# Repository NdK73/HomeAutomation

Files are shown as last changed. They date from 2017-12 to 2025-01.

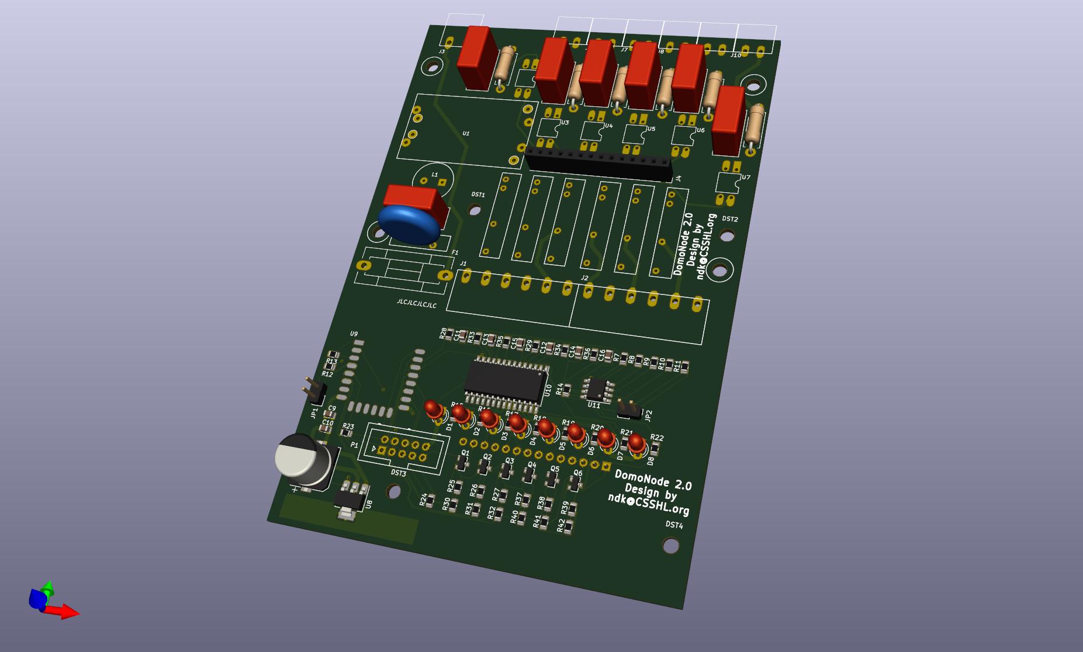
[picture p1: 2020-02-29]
domonode2.0/domonode2.0.jpg

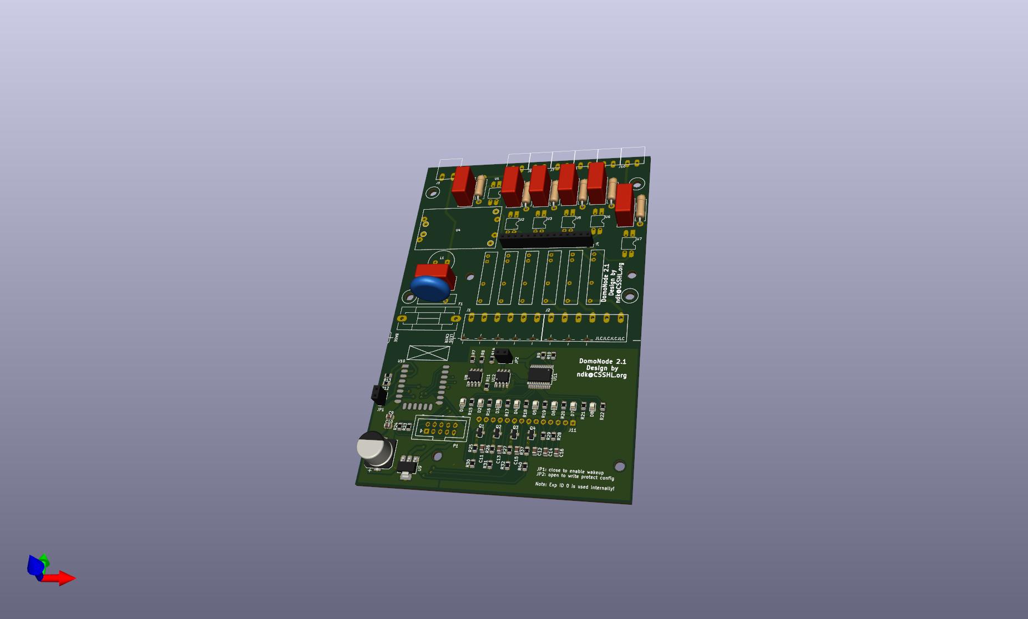
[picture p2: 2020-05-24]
domonode2/domonode2.jpg

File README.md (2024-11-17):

# HomeAutomation

This project consists of a protocol spec, the design files for physical nodes and the source code that glues it together.

## Protocol

[Full protocol description](protocol/protocol.txt) is available, together with examples of a [monitor](protocol/dom-monitor.py) and a [sender](protocol/dom-send.py). The protocol is text-based to ease debugging.

**ClearSky technology inside**: the basic concept is that **no coordinator** is needed for the nodes to work after the initial configuration. There must not be a single point of (catastrophic) failure. And obviously no "cloud" (hence **ClearSky**) service is needed either: you, and only you, decide if/when/which data can exit from your network!

The most critical element is currently the access point, that is so cheap that having a cold-standby one should not be a problem.

Messages must support authentication and encryption to guarantee that confidential packets or dangerous commands are actually sent from an authorized source.

**Warning**: protocol is still **work in progress** and **unstable**: non-backward-compatible changes are still possible! Only after 1.0.0 milestone changes that introduce incompatibilities will be delayed till 2.0.0 .

## HW

All HW designs were in [KiCAD](https://kicad.org/) 4.0.x (will follow what's packaged in latest [Ubuntu LTS](https://www.ubuntu.com/)) so not to require nonstandard installs. But 5.x introduced too many new features not to be used, and it's "easy enough" to install ([official instructions](https://kicad.org/download/ubuntu/)).

DIN-rail mounted devices are designed for the 6-modules [AK-DR-04C enclosure](https://www.aliexpress.com/item/-/1733706262.html). **Note:** these enclosures won't fit in a standard DIN rail box, unless you can move the rail further from the front panel (like in Gewiss GW40030).

Other devices are designed to be compatible with Vimar Plana series, but should fit other series with minor adjustements.

In the given layouts I use KF2EDGK **right-angle** (KF-2P, KF-4P or KF-6P) 5.08mm (or 3.81mm) pitch connectors so I can detach the node from power without having exposed wires with dangerous voltage laying around (and can reconnect it quickly and safely). Be sure to buy the angled version or you'll have a lot of extra work to bend the pins!

**Warning**: I did my best to keep the costs down without sacrificing security. Choice of the power brick is really important for security: **never** use HLK-PM01 clones unless you know what you're doing -- and even then it's better to avoid using 'em! If in doubt buy directly from [Hi-Link](http://www.hlktech.net/) (sorry, plain http, not https...). Probably the boards can't pass CE certification [only because of conducted emissions](https://skippy.org.uk/revisiting-the-hlk-pm01/), but since I don't have access to test equipment **use at your own risk** (or have 'em certified).

SSRs and relays should always be sourced from reputable sources. If in doubt, do not load 'em near the limits. For example never try a 400W load on a 2A SSR -- use a servo-relay. 2A SSRs are good for a couple of LED lamps, or a 40W bulb.

### [DomoNode](domonode) 1.1

A node based on ESP8266 to be mounted in a 6-modules DIN rail enclosure.

Provides 4 SSR outputs and an expansion bus connector.

[OSHW] IT000001 | [Certified open source hardware](https://oshwa.org/cert)

#### Errata

 - The text for GPIO4 and GPIO5 are reversed in the ESP12 symbol.

### [DomoNode 2](domonode2) 2.1 (WIP)

Evolution of DomoNode, but offers 6 inputs @ 230V, 6 SSR 2A@230V (each one have its own independent in and out lines, for maximum flexibility) and 8 independent LEDs, still in a 6-modules DIN rail enclosure. Kept SW compatibility with basic DomoNode (just the first 4 outputs), but different external connections.

To better follow the norms, now inputs are on the top and outputs at the bottom.

Same expansion bus connector as the DomoNode 1.1.

I kept 2mm between L and N lines and it **ought** to be double-insulation, but it's actually not required: the user can't touch anything that is not already expected to be at 230V (screws in connectors) without opening the enclosure (the expansion connector **MUST NOT** be exposed).

The board requires two v-cuts around the central part, drawn on ECO2 layer (but not visible in the image). Once the two boards gets separated, the smaller one have to be mounted over the bigger one, using 2 M3x25mm **plastic** spacers and suitable 1x14 pins headers (I used 2 1x14 female headers on the boards and 1x14 male pin strip with 21mm long pins to connect the two headers).

**Notes**:
 - Designed in KiCAD 5.1.5.
 - You can probably omit C8 quite safely

#### Errata

 - **Use 1k for R15-R22** or D1-D8 will burn after some months of use

#### Changes from (deprecated) [2.0](domonode2.0)
 - No glitches at powerup on outputs: all outputs are off until told otherwise by FW
 - Uses PCA9555 instead of MCP23017 (smaller, cheaper and already used for other expanders = smaller code footprint)
 - PCA9555 requires less components (pullups are included and outputs can directly drive SSRs)
 - wider traces (6mils were really too thin)
 - added socket for authentication chip (ATSHA204A or ATECC608A)
 - slightly moved connectors to better fit enclosure; probably some extra cuts to better accomodate connectors will be required anyway
 - replaced through-hole LEDs with SMD 0805 ones, better suited for light guides
 - highlighted pin 1 side for SMD IC footprints
 - corrected SDA and SCL pin assignment to use Wire.begin()
 - reduced confusing level semantics: relays and LEDs are ON when writing a HIGH level to the port (required to keep compatibility with FW for DomoNode 1.1), inputs are active when reading a LOW level (can be inverted via PCA9555)
 - used the PCB part with JLCPCB order number as a guide for LED holes: align "BASE" to the bottom of the concave part at the top of the box cover and use "LEDS CNTR" line to mark LEDs center line, then rotate the ruler and use markers on the short edges as a reference for the center line of the holes (the side opposite to "BASE" must be in contact with the right side of the concave part)
 - includes (yet untested) lightguides design files, ready to be sent to laser cutting service (use 5mm transparent plexiglas)
 - includes sample code (just add your FSM; webserver already accepts clicks on relay status to toggle it; config editing not yet implemented)

### [DomoNode-inout](domonode-inout) 1.1.1

An expansion node to be mounted in a 6-modules DIN rail enclosure.

Provides 4 SSR outputs, 3 220V opto-isolated inputs and 8 5V GPIOs.

Uses a PCA9555 for GPIOs and a 24C02 to store the expander config.

[OSHW] IT000002 | [Certified open source hardware](https://oshwa.org/cert)

### [DomoDisp](domodisp) 1.1

A node based on ESP8266 that provides physical user interface to the system.
Uses a 1.8" ST7735 LCD color display and a rotative encoder.
It is designed to be mounted either on the front of a DIN rail box, inside
a 4-modules Vimar Plana frame -- other frames could work but are untested, or
with the supplied enclosure in a 504 (4-modules) wall box.

Requires a 5V power source (possibly a DomoNode-inout, but a dedicated module
with power and relay will be published as soon as it's ready).

Includes sample "lib" for reading the encoder (needs cleanup... there still
are traces of experiments I did to read ESP's ADC from an interrupt routine).

The display can be managed by [TFT_eSPI](https://github.com/Bodmer/TFT_eSPI)
lib and works up to 27MHz (only 10MHz when testing on breadboard) -- remember
to edit User_setup.h before compiling your sketch!

[OSHW] IT000003 | [Certified open source hardware](https://oshwa.org/cert)

#### Errata

 - The text for GPIO4 and GPIO5 are reversed in the ESP12 symbol.

### [DomoDispV2](domodisp2) 2.0

**Future** release using shared SPI bus for display, freeing 2 GPIOs. One of
the freed GPIOs is used to control dimming.

**WARNING**: FW is incompatible with old DomoDisp!

### [DomoNode-inputs](domonode-inputs) 1.0

WIP - Still untested !

An expansion board with 11 inputs @ 220V and 5 low-voltage IOs.

When inputs are powered from 220V they get read as logic low.
Low-voltage inputs are directly connected to PCA9555 lines so there's a weak
(100k) pullup active at powerup. If you want to use 'em as outputs remember
to use inverted logic to avoid glitches at powerup.

### [DomoSwitch](domoswitch) 1.0

WIP / On hold (I'd need to source a suitable front panel, first)

A node that hosts 2 relays (or SSRs -- double footprint), 2 pushbuttons and 2
RGB LEDs. Split in 3 sub-boards to fit behind a 2-modules
[Vimar Plana 14042 hole cover](https://www.vimar.com/it/it/catalog/product/index/code/14042).

The buttons and LEDs are placed so that they match the markers inside the 14042
cover, simplifying the assemply.

To be compliant with SeeedFusion rules, I had to split the 3 sub boards as different designs.
Then I simply combined the sub-boards to better use the 100x100mm area. That means that for
$15 plus shipping I get 40 complete boards... I hope it doesn't require major mods!

**TODO**: support to enclose the dangerous sub-boards (I'll have to prototype it
with a 3D printer, but will need a resin cast for the final version).

### 3rd-party devices

It's obviously possible to support 3rd-party devices like SonOff, Shelly, touch switches and so on.
Reversing and further info is usually published first on [my site](https://csshl.net) (mostly Italian-only)

## SW

Still work in progress.

A sketch with [partial protocol implementation](https://github.com/NdK73/Domotic)
is under test.

Expansions (DomoNode-inout, DomoNode-inputs) are autodetected and (mostly)
autoconfigured by library. The algorithm is:
  - for each I2C bus address from 0x50 to 0x57
    - if slave found at 0x5X:
      - determine memory size:
        - try reading location 0-4 using 8-bit address (24LC02)
        - try re-reading the same locations, still using 8-bit addresses
        - both reads are equal => 8-bit addresses
        - else
          - set flag for 16-bit addresses
          - read locations 0-4 using 16-bit address (that would overwrite
          location 0 in 8-bit devices, but we already ruled out this
          is a 8-bit one...)
      - check first two bytes for 'magic' constant; if wrong, go to next
          address: not a device we can handle (possibly uninitialized)
      - read device config from it
    - if slave is not found at 0x5X, test if a slave is present at 0x2X
      (PCA9555 in DomoNode-inout 1.0)
      - if PCA9555 is found, create a fake config for 4 outs and 3 ins (TODO:
        how to handle other GPIOs?)
    - instantiate the correct device class

This algorithm assumes the memory have already been initialized.
The EEPROM must contain at least these 16 bytes:
  - 0x00 2 bytes 'magic' 0xD74A (0xD7 in 0x00 and 0x4A in 0x01)
  - 0x02 1 byte Expansion type (Official "registry" is kept in lib sources)
  - 0x03 1 byte Release code (every new HW release increments the release code)
  - 0x04 4 bytes "unique" board ID
  - 0x08 8 bytes reserved

The remaining space is used as defined by device class (usually for IO
configuration and descriptions).
The board ID must be "unique enough" so that the master node can detect that an
expansion have been changed and invalidate the old mappings.

## [Crypto HW](SecurityChips/)

I added to the repository all the informations I found re: security chips that could be used w/o signing NDAs. The list is probably incomplete.

I'm currently working on ATECC608A, trying to reverse engineer the information that would require signing NDA (why, Microchip? WHY??? you opened the docs for the 508...)

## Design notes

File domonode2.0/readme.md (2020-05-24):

## DomoNode 2.0

**Do not use:**. This folder is just for reference.

Evolution of DomoNode, but offers 6 inputs @ 230V, 6 SSR 2A@230V (each one have its own independent in and out lines, for maximum flexibility) and 8 independent LEDs, still in a 6-modules DIN rail enclosure. Kept SW compatibility with basic DomoNode (just the first 4 outputs), but different external connections.

Same expansion bus connector as the DomoNode 1.1.

I kept 2mm between L and N lines and it **ought** to be double-insulation, but it's actually not required: the user can't touch anything that is not already expected to be at 230V (screws in connectors) without opening the enclosure (the expansion connector **MUST NOT** be exposed).

The board requires two v-cuts around the central part, drawn on ECO2 layer (but not visible in the image). Once the two boards gets separated, the smaller one have to be mounted over the bigger one, using 2 **plastic** spacers (M3x15mm) and suitable 1x14 pins headers.

**Note**: Designed in KiCAD 5.1.5.

#### Known Problems

Fixed in v2.1:
 - **EPIC FAIL**: pulldowns instead of pullups on SDA and SCL :( -- it seems to work OK with internal ones, but could be a bit less stable
 - **FIXABLE FAIL**: SDA and SCL are reversed -- use Wire.begin(5,4);
 - Possible glitches at powerup on outputs: after a short power fail (~5s) MCP23017 outputs remain in the last state till setup() resets 'em (or indefinitely if you enter programming mode)
 - Trace for 3v3 to expansion connector is too thin
 - Traces from SSRs to Qn and from Qn to GND are too thin
 - Many traces are too long (to avoid vias)
 - You'll have to cut out about 2mm from the top of the break-out zone to allow the locks on the removable part of the connectors to engage

No need to fix in 2.1:
 - MCP23017 reset line goes to 3v3 instead of 5V

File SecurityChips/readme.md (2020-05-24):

# Security Chips

This folder contains developement notes and references to the needed personalization of the supported security chips (coprocessors).

## Included

Nothing yet. SW only.

## WIP

### ATECC608A

I2C address: **0x60**

16 key slots, supporting
 - NISTP256 curve for ECDH, key-derivation and signature
 - AES keys
 - Secrets for SHA

Since full datasheet is not freely available for ATECC608A, the results are obtained by reverse engineering from the publicly available datasheets and code:
 - [ATSHA204A official datasheet](ATSHA204A-Data-Sheet-40002025A.pdf)
 - [ATECC508A **full** datasheet](ATECC508A.pdf)
 - [ATECC608A **brief** datasheet](ATECC608A_(brief).pdf) (too bad the full one is under NDA)
 - [Microchip AN2589](ATECC608A-AN2589.pdf) for some more details about config area changes
 - [SparkFun_ATECCX08a_Arduino_Library](https://github.com/sparkfun/SparkFun_ATECCX08a_Arduino_Library)
 - Microchip's [cryptoauthlib](https://github.com/MicrochipTech/cryptoauthlib) and [cryptoauthtools](https://github.com/MicrochipTech/cryptoauthtools/)
 - [atecc608a python lib source](https://github.com/ergo70/atecc608a)
 - [ECC608-AES-GCM-Test](https://github.com/kmwebnet/ECC608-AES-GCM-test)

Slot allocations:
 - 0: device private key for attestation (ECDH=0, Internal sigs=1, External sigs=0), **must be locked after generating key**
 - 1: device private key for ECDH (ECDH=1, Internal sigs=0, External sigs=0), **must be locked after generating key**
 - 2: 1st base station's PK for ECDH
 - 3: 2nd base station's PK for ECDH
 - 4: Master secret 1 (node-bs1) (written by ECDH 1+2)
 - 5: Shared key 1 (derived from key 4 via KDF)
 - 6: Master secret 2 (node-bs2) (written by ECDH 1+3)
 - 7: Shared key 2 (derived from key 6 via KDF)
 - 8-15: Group secrets for SHA

Generate device attestation certificate:
 - generate key 0: GenKey(0b00001100 /* Generate digest in TmpKey, new random private key */, 0x0000 /* Keyslot * */ ), check return value (might fail); save returned pubkey (64 bytes, X,Y)
 - generate self signed certificate: Sign(0x80 /* InternalSig */, 0x0000 /* Keyslot 0 */); save result (64 bytes, R,S)

Verify device attestation certificate:
**TODO**

#### Python code

The code uses 

## TBD

### ATSHA204A

I2C address: **0x64**

Not being able to do actual crypto, it requires  **secure initialization** of the shared secret.
Depending on your security requirements it can range from easy to very difficult.

References:
 - [ATSHA204A official datasheet](ATSHA204A-Data-Sheet-40002025A.pdf)

### SE050

NXP SE050 (SE050C1 variant) is in a not very hobbyst-friendly package but supports all ECC curves, including Curve25510/Ed25519, **and** RSA up to 4096 bits.
A1 variant only supports ECC curver, B1 variant only RSA.

### DS2477 / DS28C50

Just supports SHA3 for authentication, no crypto. Similar to ATSHA204, but from Maxim.

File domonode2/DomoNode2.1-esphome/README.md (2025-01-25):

# Use DomoNode 2.1 from ESPHome

Recently ESPHome started supporting TCA9555 expander (currently input changes are not reported, see [this thread](https://github.com/esphome/issues/issues/6438#issuecomment-2560802722) for a fix): that greatly simplifies integrating a DomoNode 2.1 in Home Assistant.

The HW template to use is [DomoNode21.yaml](DomoNode21.yaml) . Just save it under esphome/ folder (I usually store board definition files in esphome/boards/DomoNode/) and create your device as:

    substitutions:
      device_name: test
      upper_devicename: Test
    
    packages:
      domonode: !include boards/DomoNode/DomoNode21.yaml
    
    esphome:
      name: $device_name
    
    # Enable Home Assistant API
    api:
      encryption:
        key: "useASecureKey"
      reboot_timeout: 0s
    
    ota:
      - platform: esphome
        password: "BetterHaveAGoodKeyHereToo"
    
    # A web page is useful...
    web_server:
      port: 80
      version: 2
    
    # You can also override the settinsg like:
    output:
      - id: !extend led1
        invert: true
    light:
      - id: !extend rl1
        name: "Main Power line"

EEPROM is also supported by [this component](https://github.com/pilotak/esphome-eeprom), just add to your yaml this snippet:

    external_components:
      - source: github://pilotak/esphome-eeprom
        components: [i2c_eeprom]
    
    i2c_eeprom:
      - id: eeprom0
        size: 2KB # Default mainboard memory (kilobits!)
        #address: 0x50

Too bad there's no support (yet) for the crypto chip.

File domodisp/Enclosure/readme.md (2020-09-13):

# DomoDisp Enclosure

In this folder you can find the enclosure I designed for DomoDisp both in FreeCad and STL formats.

It's sized for a 504 (4-modules) wall box.

I printed Front.stl "upside down". If your settings are OK for the filament you're using, it should print well w/o supports.

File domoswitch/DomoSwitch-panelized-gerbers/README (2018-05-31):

Used Panelizer (from GerberTools).
Requires renaming two files from KiCad's plots: .gm1 to .gml and .drl to .txt *before* combining boards.

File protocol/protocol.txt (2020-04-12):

Domotic protocol (version 0.1.1)
================================

When using IP as transport layer, every node must have its own address and must be able to receive and send data *only* from/to the local network.
This protocol is *not* intended to be exposed to the Internet, even if some (limited) coutermeasures are implemented: multicast TTL is 1, longer answers require authenticated requests, etc. If accessibility from the Internet is needed, a gateway with proper security measures (SSL encryption, proper authentication, etc) *must* be used. The gateway can translate to other protocols, too.
The packet format is constrained by UDP on ESP8266 (reference platform) that allows at most 1472 bytes per UDP packet (a single Ethernet frame).

Default UDP port used is 55114. Default multicast address used is 239.255.215.74 (see RFC2365 "The IPv4 Local Scope", the last two octects are the integer 55114).
If needed, "fake" MAC addresses can be generated as 4e:64:4b:xx:yy:zz ('N':'d':'K':xx:yy:zz) -- least significant bits of first octect are '10', that means "locally administerd (1)" and "unicast (0)".

Every node in the network is configured with an unique ID ('sender'). 0x0000 means "unconfigured" and 0xFFFF is reserved.

Every IO line MUST be member of a groupID (see maps in registers 0x20-0x23), that is used to report its changes. ID 0000 is reserved for unconfigured IOs that MUST NOT be reported. GroupID allocation strategy is instance-specific and not covered by protocol.

Allowed characters for strings in array elements are [a-zA-Z0-9.:_-] .

Data coming throught the serial port during the initial configuration (after a hard config reset -- usually a 10-seconds press of a protected button) is considered signed and encrypted (but it's actually unsigned plaintext).

Display-enabled devices MIGHT handle "widgets" (bars, icons) as output ports (both analog and digital). If message is longer than allowed the device MUST show at least the first max_msg_len characters and MIGHT use scrolling to display the whole message.

A packet is defined as:

Pkt := UnicastPkt | MulticastPkt
UnicastPkt := RequestPkt | AnswerPkt

RequestPkt is sent from a client to a server to initiate an operation.

RequestPkt := SimplePkt | SignedPkt | EncPkt
  SimplePkt := CommandPacket | InfoPacket
    CommandPacket := <'C'> {DigitalOutSpec | AnalogOutSpec | RegisterSpec}
      DigitalOutSpec := <'D'> <output#:ByteHex> <'0'|'1'|'T'>
      AnalogOutSpec := <'A'> <input#:ByteHex> <value:WordHex>
        WordHex := <hibyte:ByteHex> <lobyte:ByteHex>
      RegisterSpec := <'R'> <reg#:ByteHex> <0x20-0x7f>* // Till end of line or end of packet; register-specific parsing required
    InfoPacket := <'I'> {DigitalReadSpec | AnalogReadSpec | InfoSpec | RegisterReadSpec}
      DigitalReadSpec := <'D'> <'I'|'O'> <io#:ByteHex>
      AnalogReadSpec := <'A'> <'I'|'O'> <io#:ByteHex>
      InfoSpec := <'I'> <'A'|'D'> <'I'|'O'> <io#:ByteHex>
      RegisterReadSpec := <'R'> <reg#:ByteHex> [<arrayelement#:ByteHex>]
  SignedPkt := <'S'> <keyID:WordHex> <signature:Array<ByteHex>> SimplePkt // TODO
  EncPkt := <'E'> <keyID:WordHex> <payload:Array<ByteHex>> // Payload can be either SignedPkt or SimplePkt, and MUST be encrypted under given key; TODO

  ByteHex := <0-9|A-F><0-9|A-F>  // Max 256 'lines' per type

AnswerPkt is sent from a server to the client that sent a RequestPkt. If it's sent, it MUST be addressed to the same IP and port that originated the RequestPkt.

In SignedPkt (and the following SignedUpdatePkt) the signature covers only payload data (SimplePkt or EventSpec), *NOT* including termination character (CR or \x00).

TODO: handle encryption (should use the same key as in request, if possible: what happens when using pubkeys?)

AnswerPkt := <'A'> ErrorCode AnswerSpec
  ErrorCode := <err:ByteHex>
  AnswerSpec := <''> | <current status string depending on received SimplePkt>

Nonzero 'err' reports an error and AnswerSpec must be empty.
If err is zero, AnswerSpec depends on SimplePkt:
  CD: <'W'> <'D'> <'0'|'1'>
  CA: <'W'> <'A'>
  CR: <'W'> <'R'>
  ID: <'R'> <'D'> <'0'|'1'>
  IA: <'R'> <'A'> <value#:WordHex>
  IR: <'R'> <'R'> {<'L'> <len:ByteHex> | <'V'> <0x20-0x7f>*}
  II: <'R'> <'I'> {InfoBool | InfoPercent | InfoTemp | InfoPower | InfoUserFloat | InfoText} <descr:<0x20-0x7f>*>
    InfoBool := <'B'>                                                   // Used for digital lines
    InfoPercent := <'%'> <decimals:0-3>
    InfoTemp := <'K'> <decimals:0-2>                                    // By default room temperatures are reported in centi-Kelvin (K2)
    InfoPower := <'W'> <decimals:0-2>                                   // Power in Watts (0.00 to 65535) -- usually home appliances use decimals=0 (1W resolution)
    InfoUserFloat := <'F'> <numerator:WordHex> <denominator:WordHex>    // Float=(numerator*regvalue)/(denominator*65536); note that result is strictly < numerator/denominator
    InfoText := <'T'> <maxlen:ByteHex>

MulticastPkt can be generated either in response to some external event (a change in temperature, a timer expiring, ...) or in response to a RequestPkt.
Nodes can listen to multicast packets to update their state or act in response to events happened on other nodes (f.e. a light turns on when a button on another node is pressed).

Note that setting the node HW config (which lines are inputs, which are outputs, their names and characteristics, etc) is outside the scope of this protocol, and nodes should not allow remote changes.

MulticastPkt:= UpdatePkt | SignedUpdatePkt
  SignedUpdatePkt := 'S' <keyID:WordHex> <signature:urlsafe_base64_string> UpdatePkt
  UpdatePkt := <'U'> EventSpec
    EventSpec := InEvent | OutEvent | TimeEvent
      InEvent := <'I'> {DigitalEvent | AnalogEvent}
        DigitalEvent := <'D'> <group:WordHex> <'0'|'1'>
        AnalogEvent := <'A'> <group:WordHex> <value:WordHex>
      OutEvent := <'O'> {DigitalEvent | AnalogEvent}
      TimeEvent := <'T'> <epoch:ByteHex> <hictr:WordHex> <loctr:WordHex> <tz_dst:ByteHex>

Analog values are represented as an unsigned 16-bits word. Temperatures should be converted in centi-Kelvin unless peculiar needs require otherwise.

TimeEvent is usually generated periodically (at least every minute, up to once per second) by a coordinator node with access to accurate timekeeping HW and/or external sources (NTP, GPS, etc). The only epoch currently defined is 00 (for Unix epoch: seconds since Jan, 1, 1970 -- will last till Jan 2106), hictr and loctr are a single 32-bit counter. tz_dst packs timezone relative to GMT in lower 5 bits (signed) and if dst is active or not in bit 5. Bits 6 and 7 are reserved and must be 0. Security-sensitive nodes must sanitize it (checking that it does not deviate too much from internal clock, adding sequence numbers to packets sent during the same second, etc) and should only trust signed updates. Time needed for signature verification *must not* "shift" the timestamp (in other words the timestamp references the second the packet have been received, not the one it gets processed).

Only "meaningful" AnalogEvent should be reported. The meaningfulness of the change is application- and sensor-specific. For example, it's usually useless to report every .01°C change in temperature for a room, but only a .1°C change -- or even a 2°C one if you're using a DHT11 (2°C error!). Rule of thumb: don't send more than a report every 10 seconds or so for a single entity to avoid flooding the network with useless data.

Registers
=========

When reading register containing arrays, if the optional argument is omitted, only the array len is returned. If the optional argument is given, then the actual element is returned.

Every write to registers must be inside a signed packet.

Changes to register contents must be saved to permanent storage before returning answer packet.

00: node info
    READ: string: "protocol_version digital_outs analog_outs digital_ins analog_ins max_txt_len utf8_support"; protocol_version is currently "0.1.1", numbers in *decimal*, utf8_support as 'T' or 'F'
    WRITE: (requires a signed packet *and* 'sender' still 0x0000) sets 'sender' (node-ID)
01: node keys & supported algorithms
    READ: Array<String>: "<keyID:WordHex>:algo=key_handle;uses", algo:='ec25519'(key exchange)|'ed25519'(sign)|'nistp256'(HW-backed, f.e. in ATECC608A)|'aes-enc'|'aes-mac'|'unset'; empty array means neither authentication nor encryption are supported, else number of slots tells the number of keys that can be used; key_handle for public and private keys is the public key (you can say if the priv key is available by looking at key usage), for secret keys is just a key handle (FIXME: define how it's generated), if the key is not yet set but the slot is reserved for a certain algo, handle can be empty; 'uses' is a string of one or more permitted uses for the given key: 'e'ncrypt, 'k'ey agreement, 's'ignature, 'v'erify signature (only pubkey is present); keys can only be set using encrypted packets or OOB; keyID 0000 is reserved for the NULL method (signature generates a sequence of 128 '0', encryption copies the source string) and *MUST* be refused in production builds; keyID FFFF is reserved and can not be used
02: hostname (short)
    READ: string: "<hostname> (<build_ID>)"
    WRITE: string, max 64 characters ([a-z0-9-], see RFC1123)
03: flags; WordHex, TODO (UdpReportEnable?) -- currently RESERVED
04: network info
    READ: string: "WIFI:SSID,ip" | "ETH:ip" | "BUS:nodeID"
    WRITE: string: "WIFI:SSID,password[,ip,mask]" (must also be encrypted) | "ETH:DHCP|ip,mask" | "BUS:nodeID" (bus must be on a different port than config interface)
05: display message
    READ: string
    WRITE: string, max max_txt_len (from R0) printable-ASCII characters (0x20-0x7e) for message
06-1f: reserved
20: digital out port map
    READ: Array<WordHex> : current mapping of digital outs
    WRITE: Array<WordHex> : sets new mapping of digital outs
21: analog out port map
    READ: Array<WordHex> : current mapping of analog outs
    WRITE: Array<WordHex> : sets new mapping of analog outs
22: digital in port map
    READ: Array<WordHex> : current mapping of digital ins
    WRITE: Array<WordHex> : sets new mapping of digital ins
23: analog in port map
    READ: Array<WordHex> : current mapping of analog ins
    WRITE: Array<WordHex> : sets new mapping of analog ins
24: (Array<Event>) events
25: (Array<?>) timer actions TODO
26: (Array<WordHex>) timers intervals; most significant nibble is: 0=Monostable|1=Astable, 00=milliseconds, 01=seconds, 10=minutes, 11=hours, 0=RESERVED; the remaining 12 bits define the actual interval
27-ff: reserved

/*************************************

 TO BE RETHOUGHT COMPLETELY !

 ||||||||||||||||||||||||||||
 vvvvvvvvvvvvvvvvvvvvvvvvvvvv

Events and timers
=================

An "event" is the reaction of a node to a *multicast* message, irregardless if it's being transmitted or received. Unicast messages don't trigger event processing.

A timer is a node-private object that (obviously) keeps track of time. It can only be started (starts from the definition in R27) and gets decremented automatically every tick (.1s = 10Hz). When it reaches 0, it fires an event. Timers need not to be very accurate (+/- a tick is still OK). Setting a timer to 0 disables it *without* firing an event. Only a single action is allowed for a timer.

Events are thought for simple actions ('turn off a light after 30 seconds'). Complex scenarios COULD be coordinated by a management node (that COULD offer a more user-friendly interface or even a programmatic one). Anyway "semi-complex" scenarios are possible even with only a limited amount of events.

Event := GroupID Condition {DigitalOutSpec | AnalogOutSpec | TimerSpec}
  Condition := <'-'> | EventCond | Timer
    EventCond := EventSpec [<'<'> | <'>'> | <'='>]  // Default is '='
    Timer := <'T'> ByteHex
    TimerSpec := Timer {<'0'> | <'1'>]
TimerEvent:= Timer DigitalOutSpec

The first match is on groupID. The second match is on Condition. '-' means the action is executed without checking anything.

Examples (spaces added for readability):
// Stepper: toggles out1 state every time digital input 4 of group 1234 goes low
1234 ID04 0      D01 T
// Control heating system with hysteresis
ABCD IA01 21C0 > D03 0  // Turn off heating if temp > 21.0°C
ABCD IA01 17C0 < D03 1  // Turn on heating if temp < 17.0°C
// Toggle out2 when in7 of node 4567 goes low for more than 1s (R28 must contain "..,..,0A,...")
4567 ID07 1      T02 0  // 4567:din7 is high: disable timer2
4567 ID07 0      T02 1  // start timer2 (multicast is sent only when the signal is changing)
T02  D02 T              // timer2 fires: toggle out2

// --Not working-- Watchdog: other nodes are powered only when out1=1
// Note that T00 is only started once a packet arrives, so even if the AP takes 10minutes to come back online it's not a problem!
*    -      T00 0384   // restart timer 00 every time a multicast packet arrives; fires after 90s (900 = 0x0384)
!    T00    D01 0      // when timer0 fires, out1 gets reset
!    T00    T01 000A   // ... and timer1 is started (1s)
!    T01    D01 1      // When timer1 expires, out1 returns to 1

*/

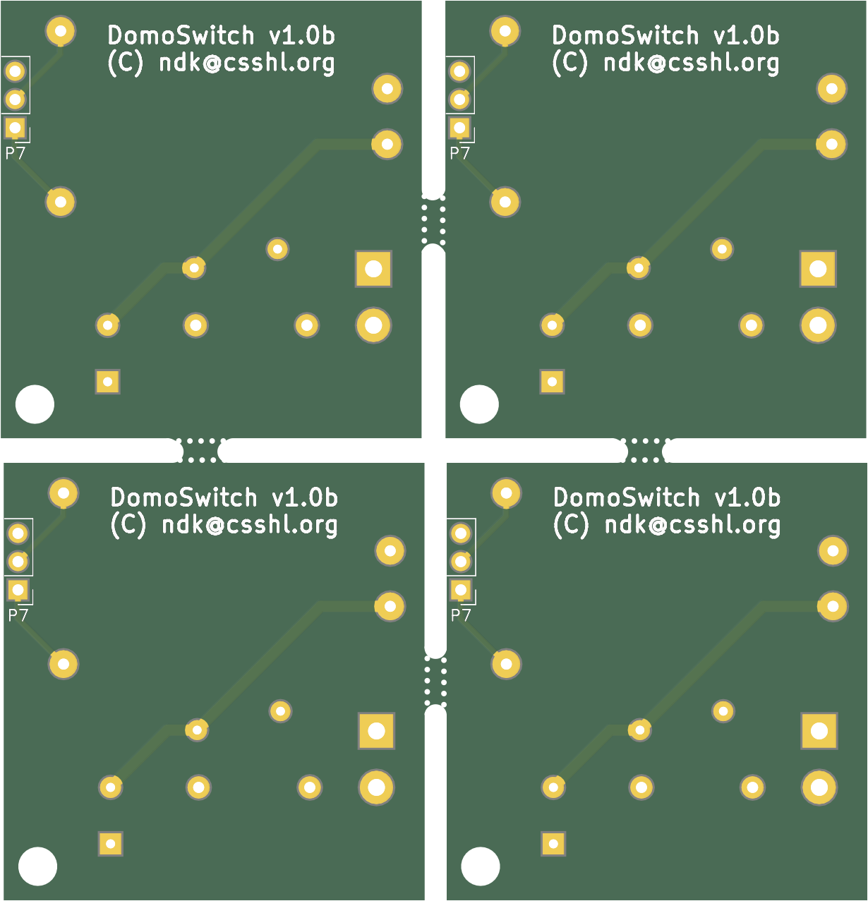
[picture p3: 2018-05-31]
domoswitch/DomoSwitch-panelized-gerbers/DomoSwitch-2_Bottom.png

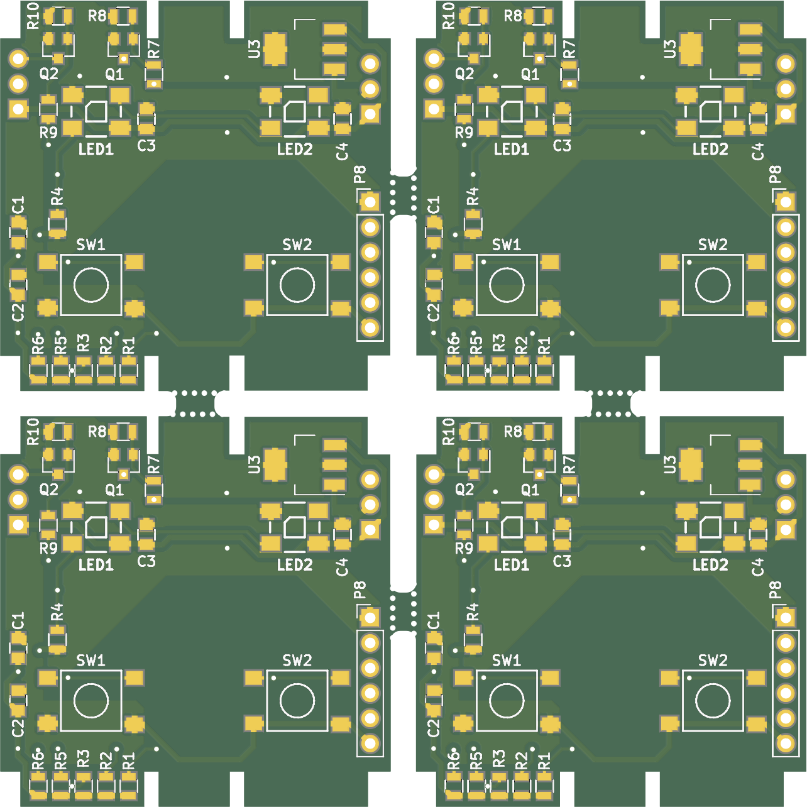
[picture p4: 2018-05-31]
domoswitch/DomoSwitch-panelized-gerbers/DomoSwitch-1_Top.png

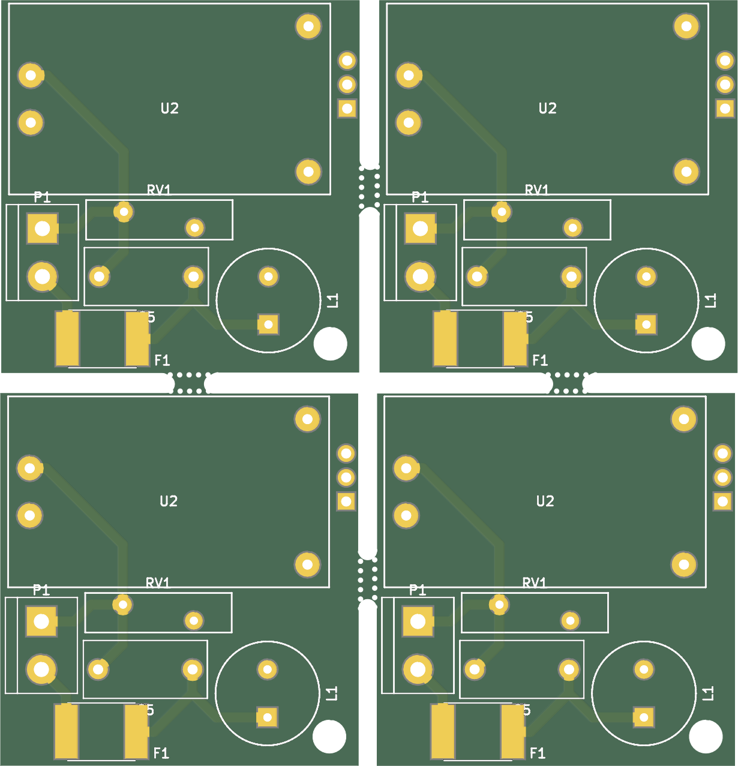
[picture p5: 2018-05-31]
domoswitch/DomoSwitch-panelized-gerbers/DomoSwitch-2_Top.png

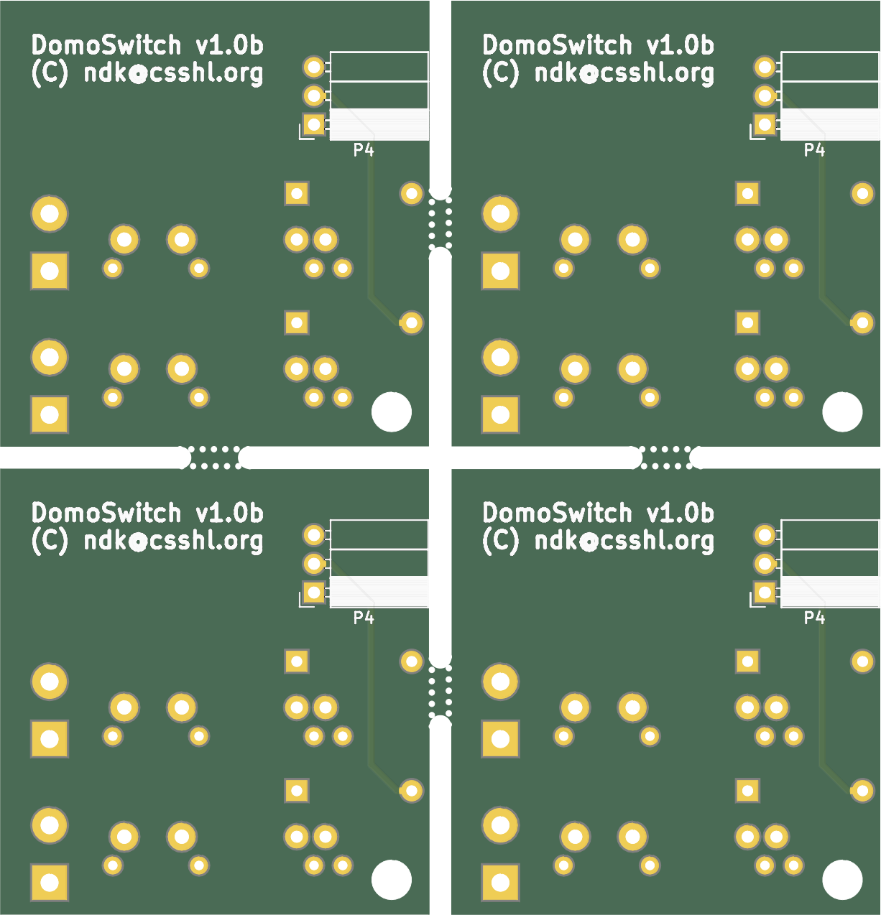
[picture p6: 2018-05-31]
domoswitch/DomoSwitch-panelized-gerbers/DomoSwitch-3_Top.png

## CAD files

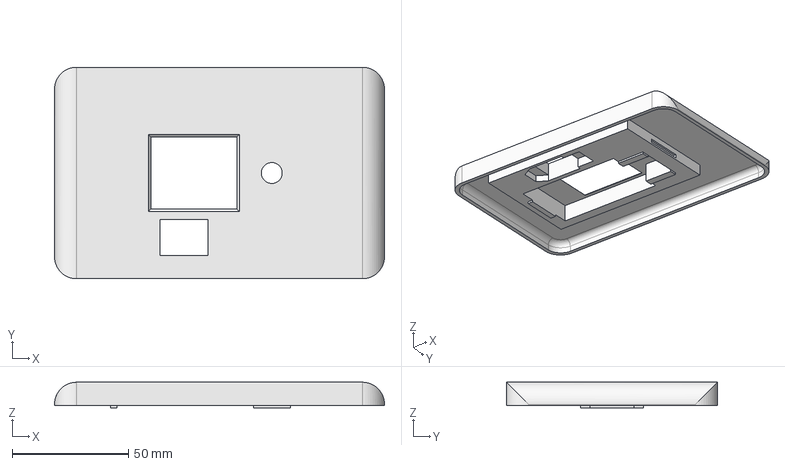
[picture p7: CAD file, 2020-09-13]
domodisp/Enclosure/Front.FCStd
142.0 x 91.0 x 11.0 mm

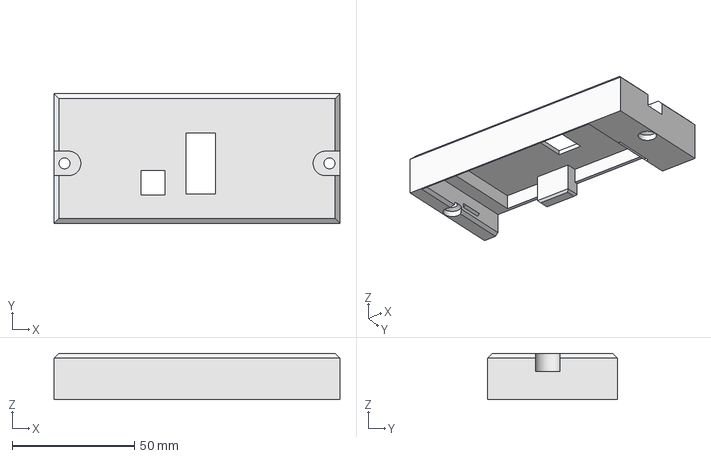
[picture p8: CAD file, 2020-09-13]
domodisp/Enclosure/Support.FCStd
117.0 x 53.0 x 19.0 mm

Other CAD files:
domodisp/Enclosure/Front.stl
domodisp/Enclosure/Support.stl

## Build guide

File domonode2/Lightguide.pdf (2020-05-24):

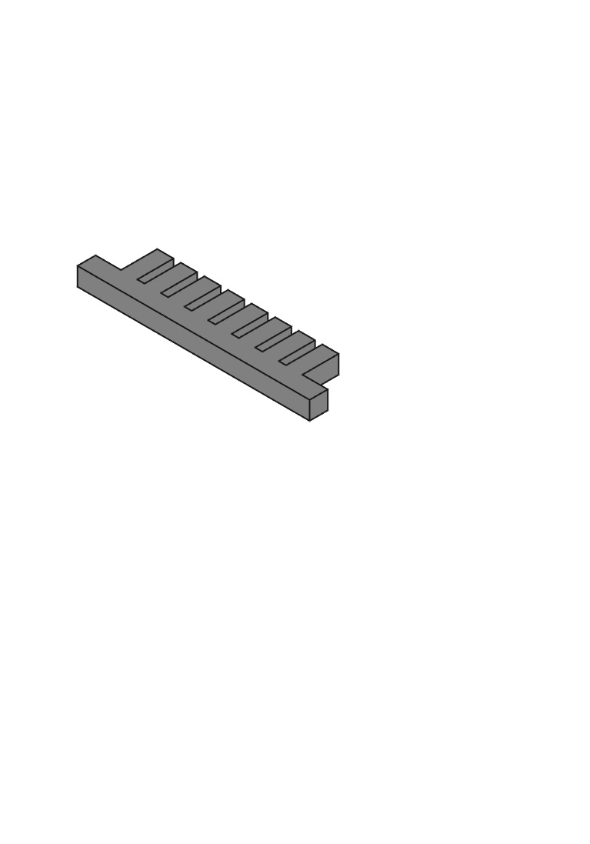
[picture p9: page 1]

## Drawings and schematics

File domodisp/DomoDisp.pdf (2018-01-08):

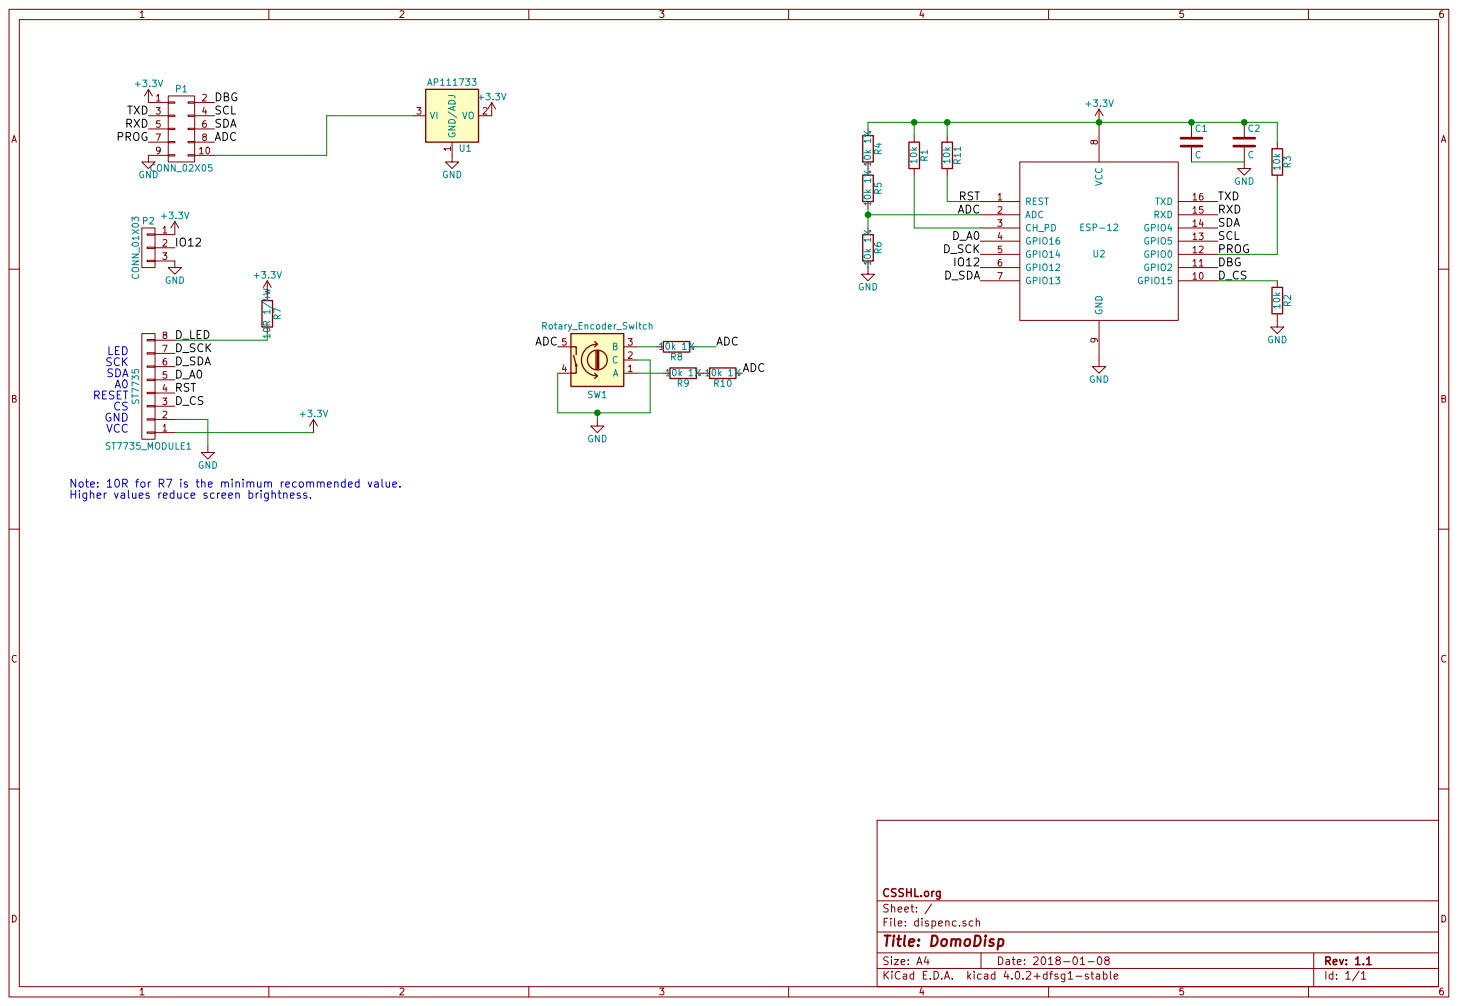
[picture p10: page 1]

9 GPIO15 10 GPIO2 11 GPIO0 12 GPIO5 13 GPIO4 14 RXD 15 TXD 16 U2 ESP-12 GND

File: dispenc.sch Sheet: / CSSHL.org

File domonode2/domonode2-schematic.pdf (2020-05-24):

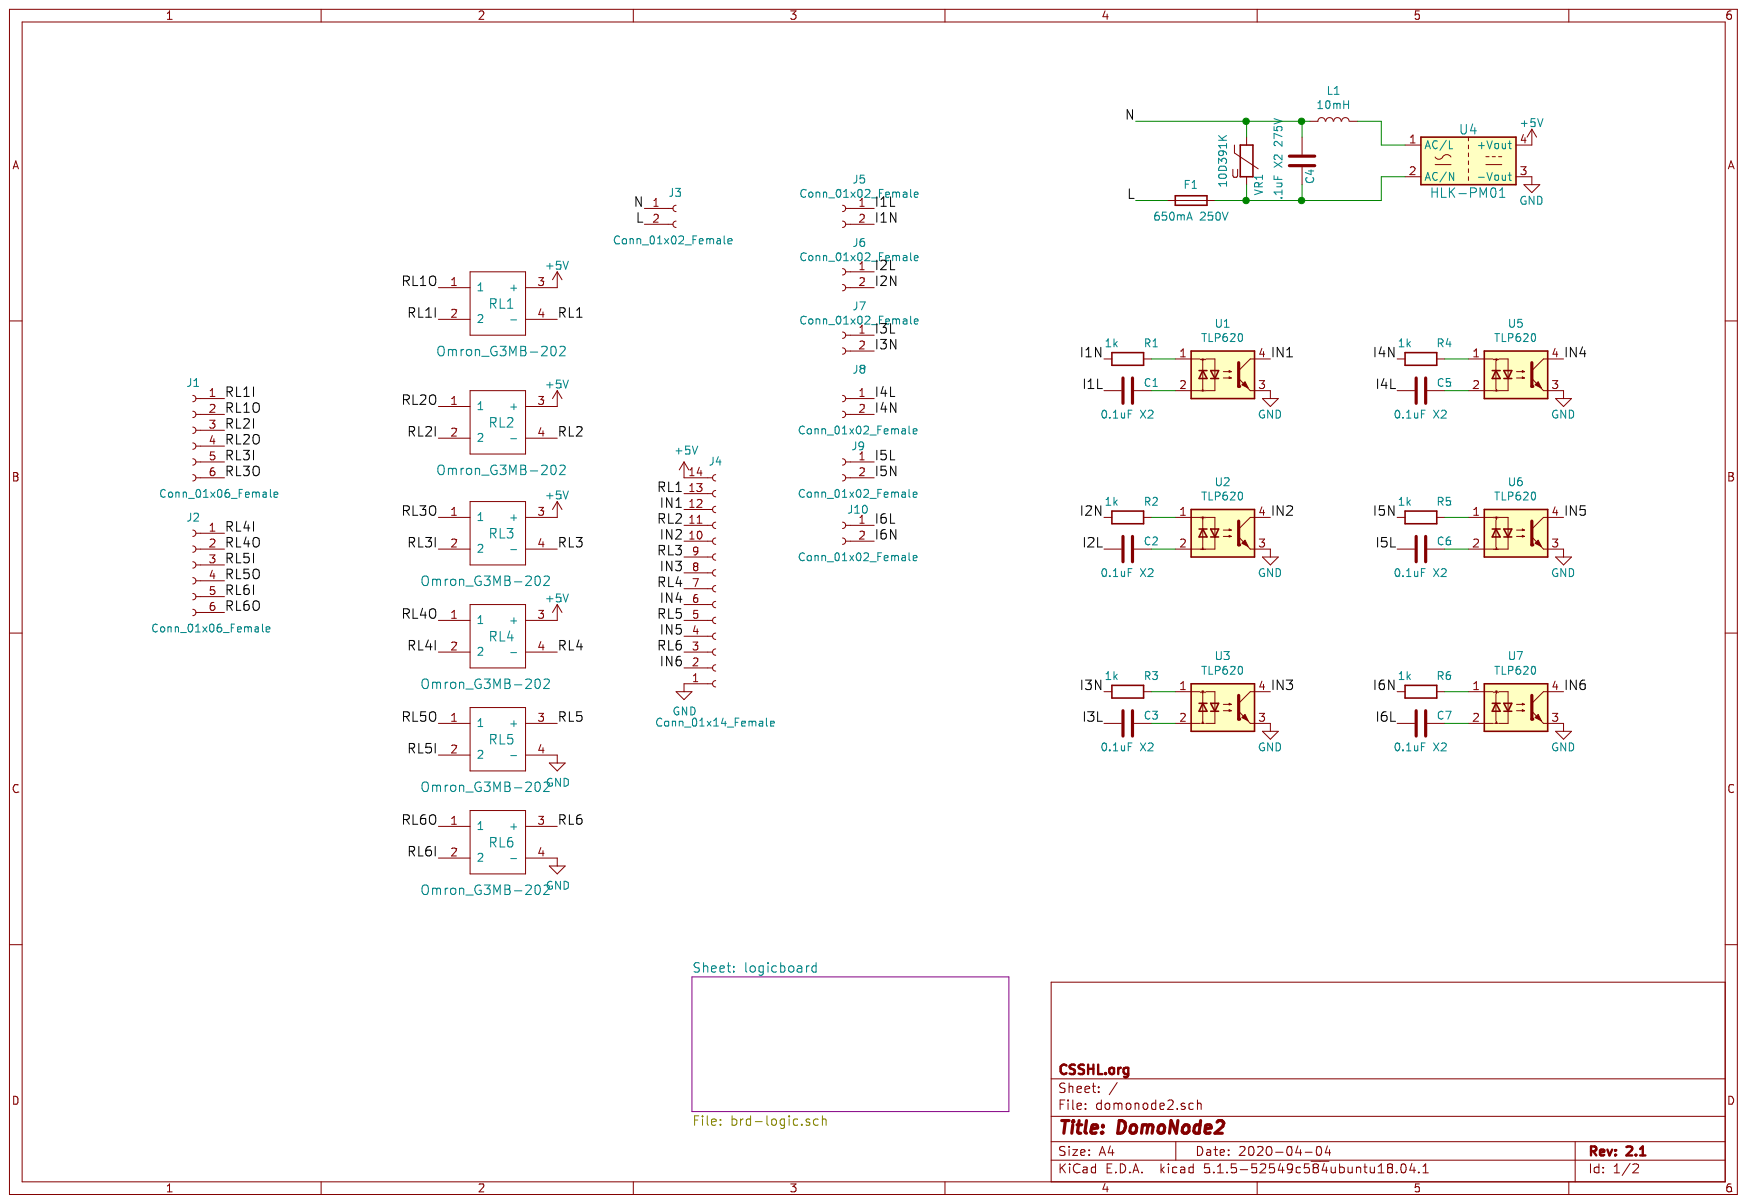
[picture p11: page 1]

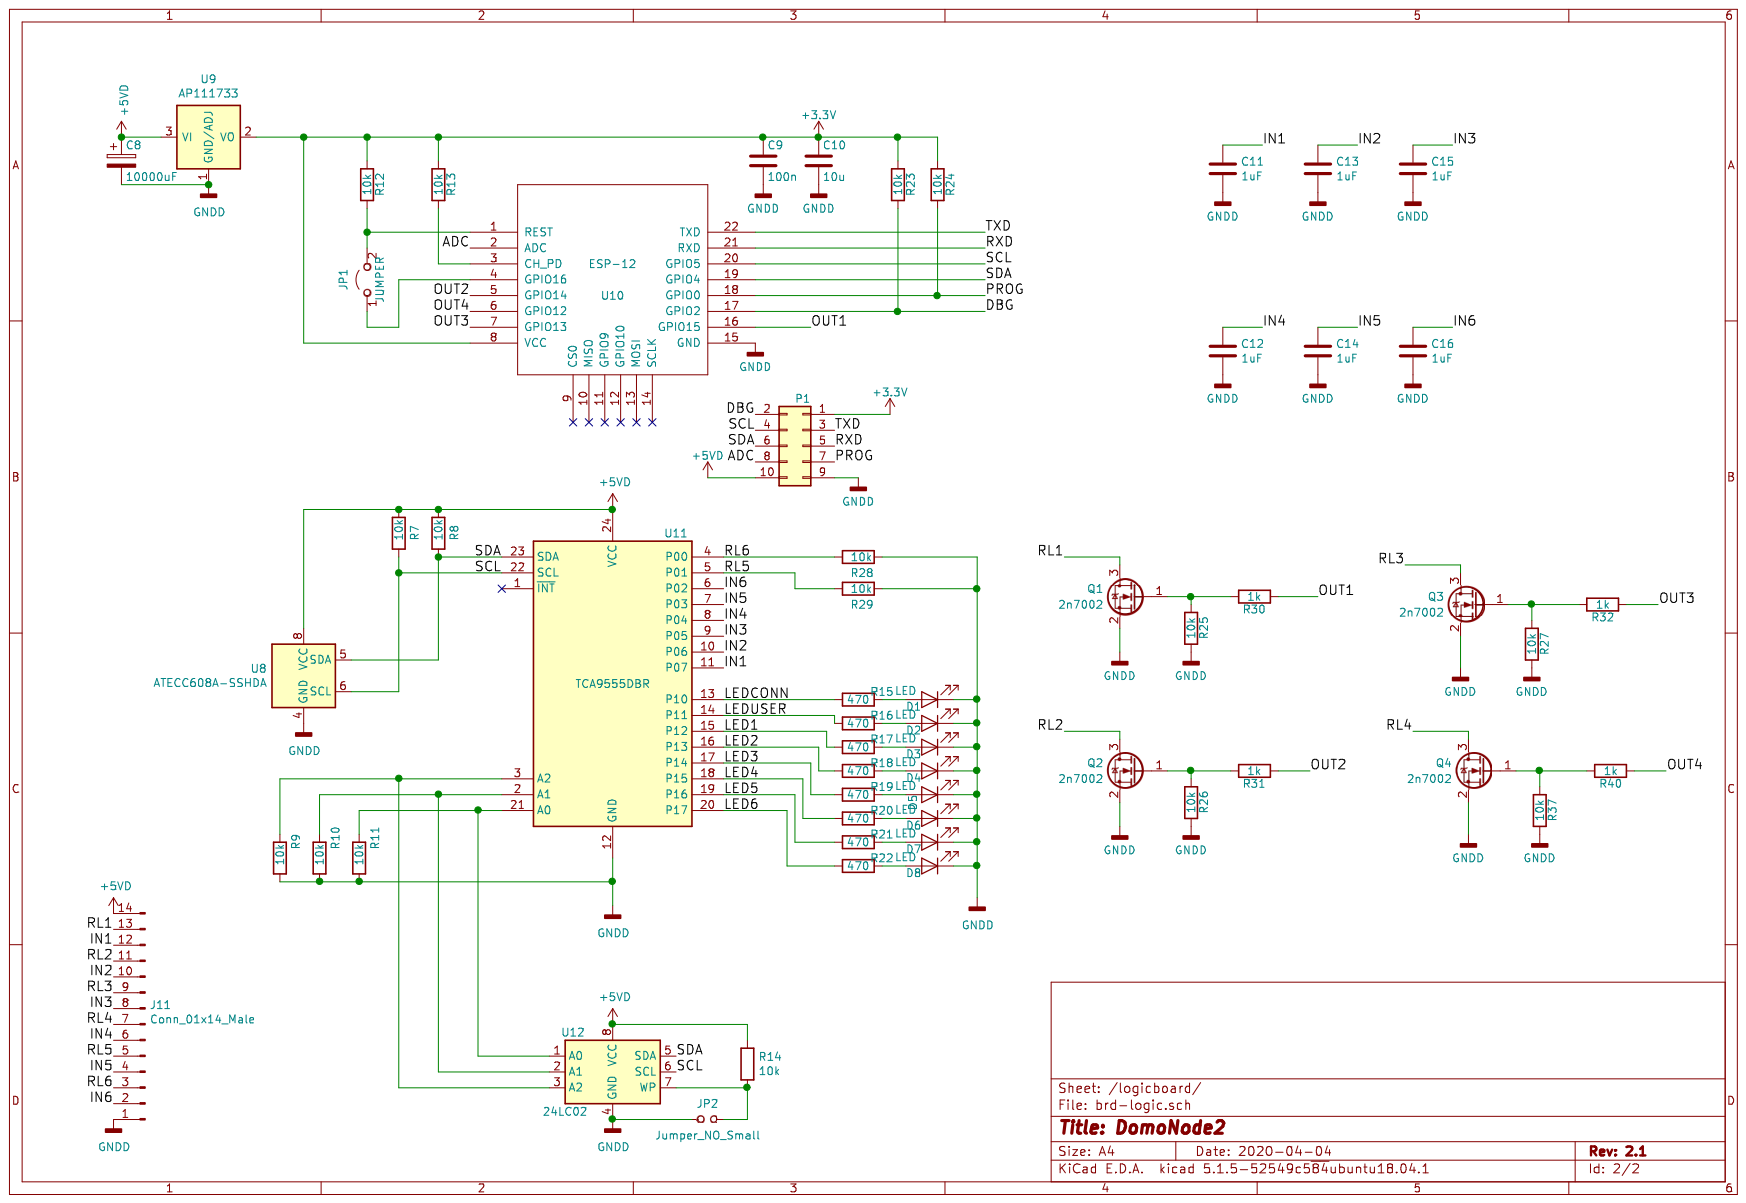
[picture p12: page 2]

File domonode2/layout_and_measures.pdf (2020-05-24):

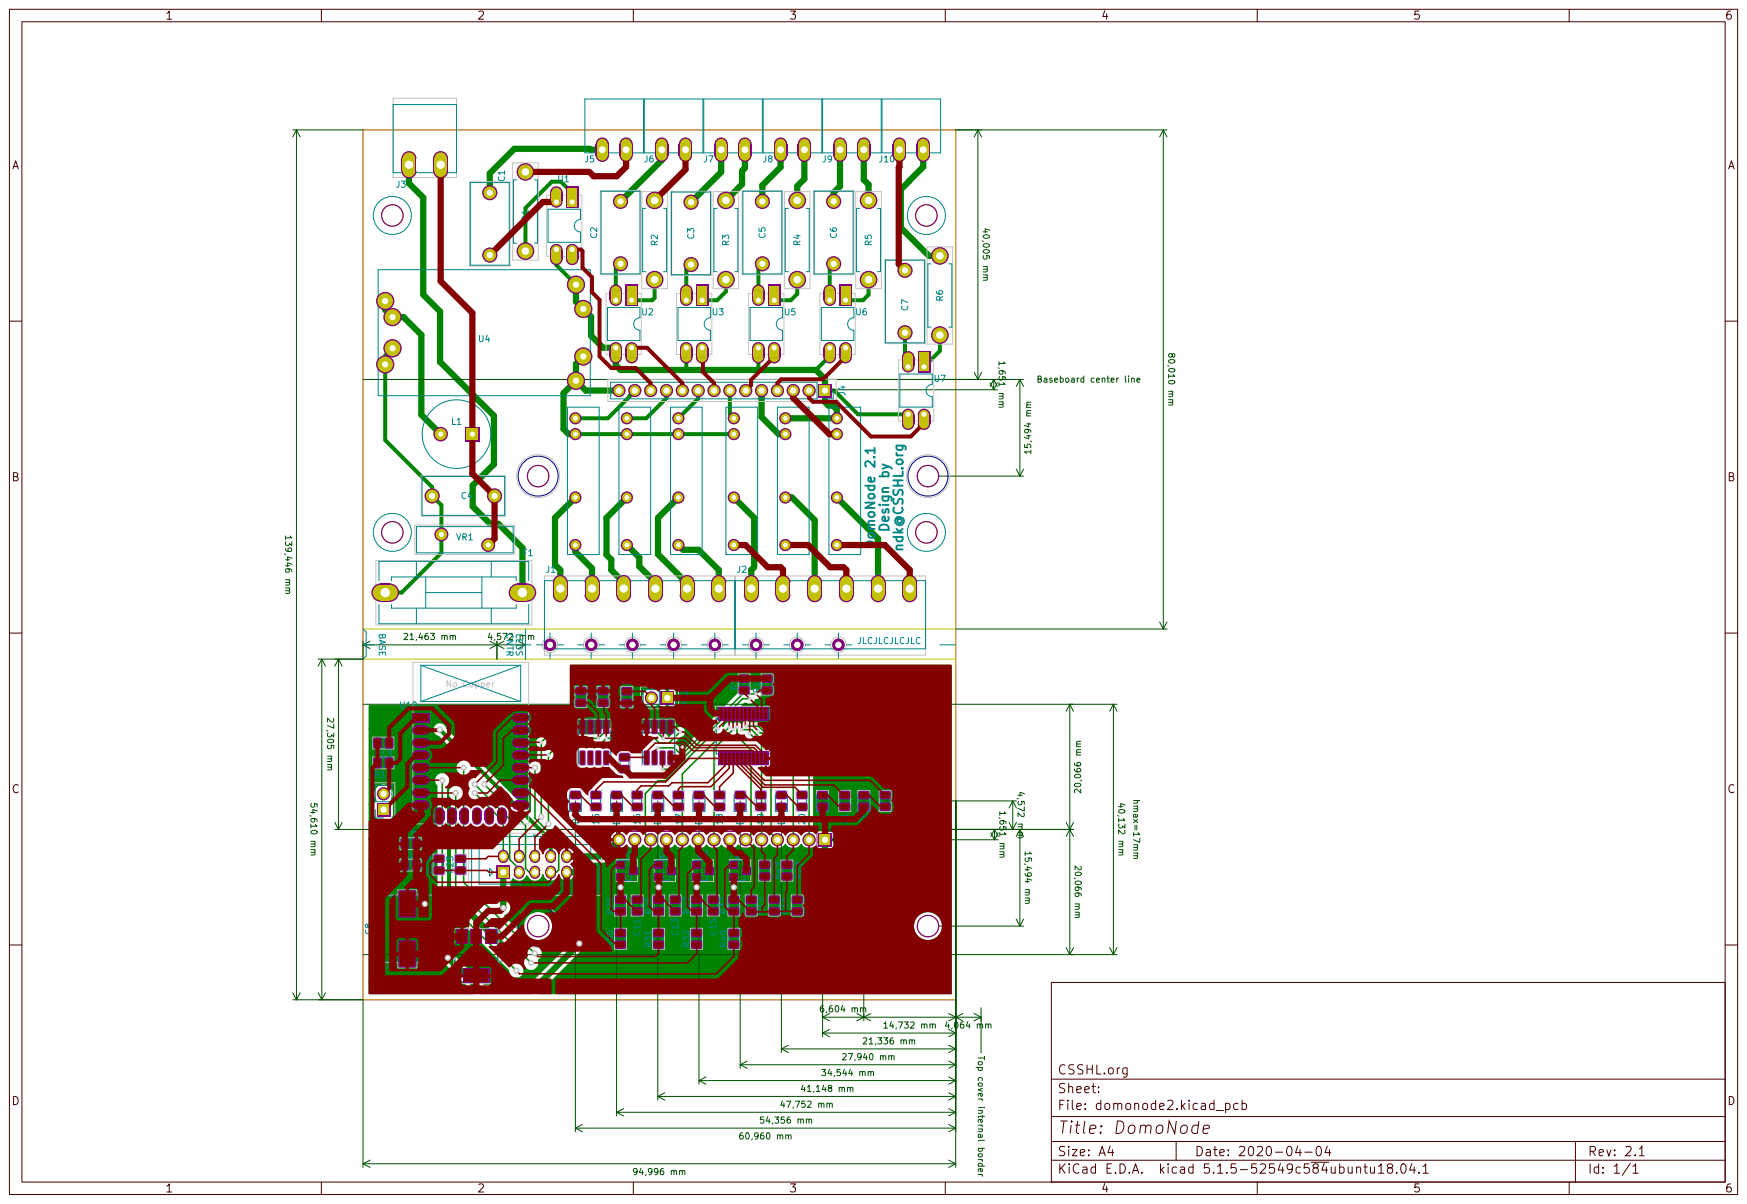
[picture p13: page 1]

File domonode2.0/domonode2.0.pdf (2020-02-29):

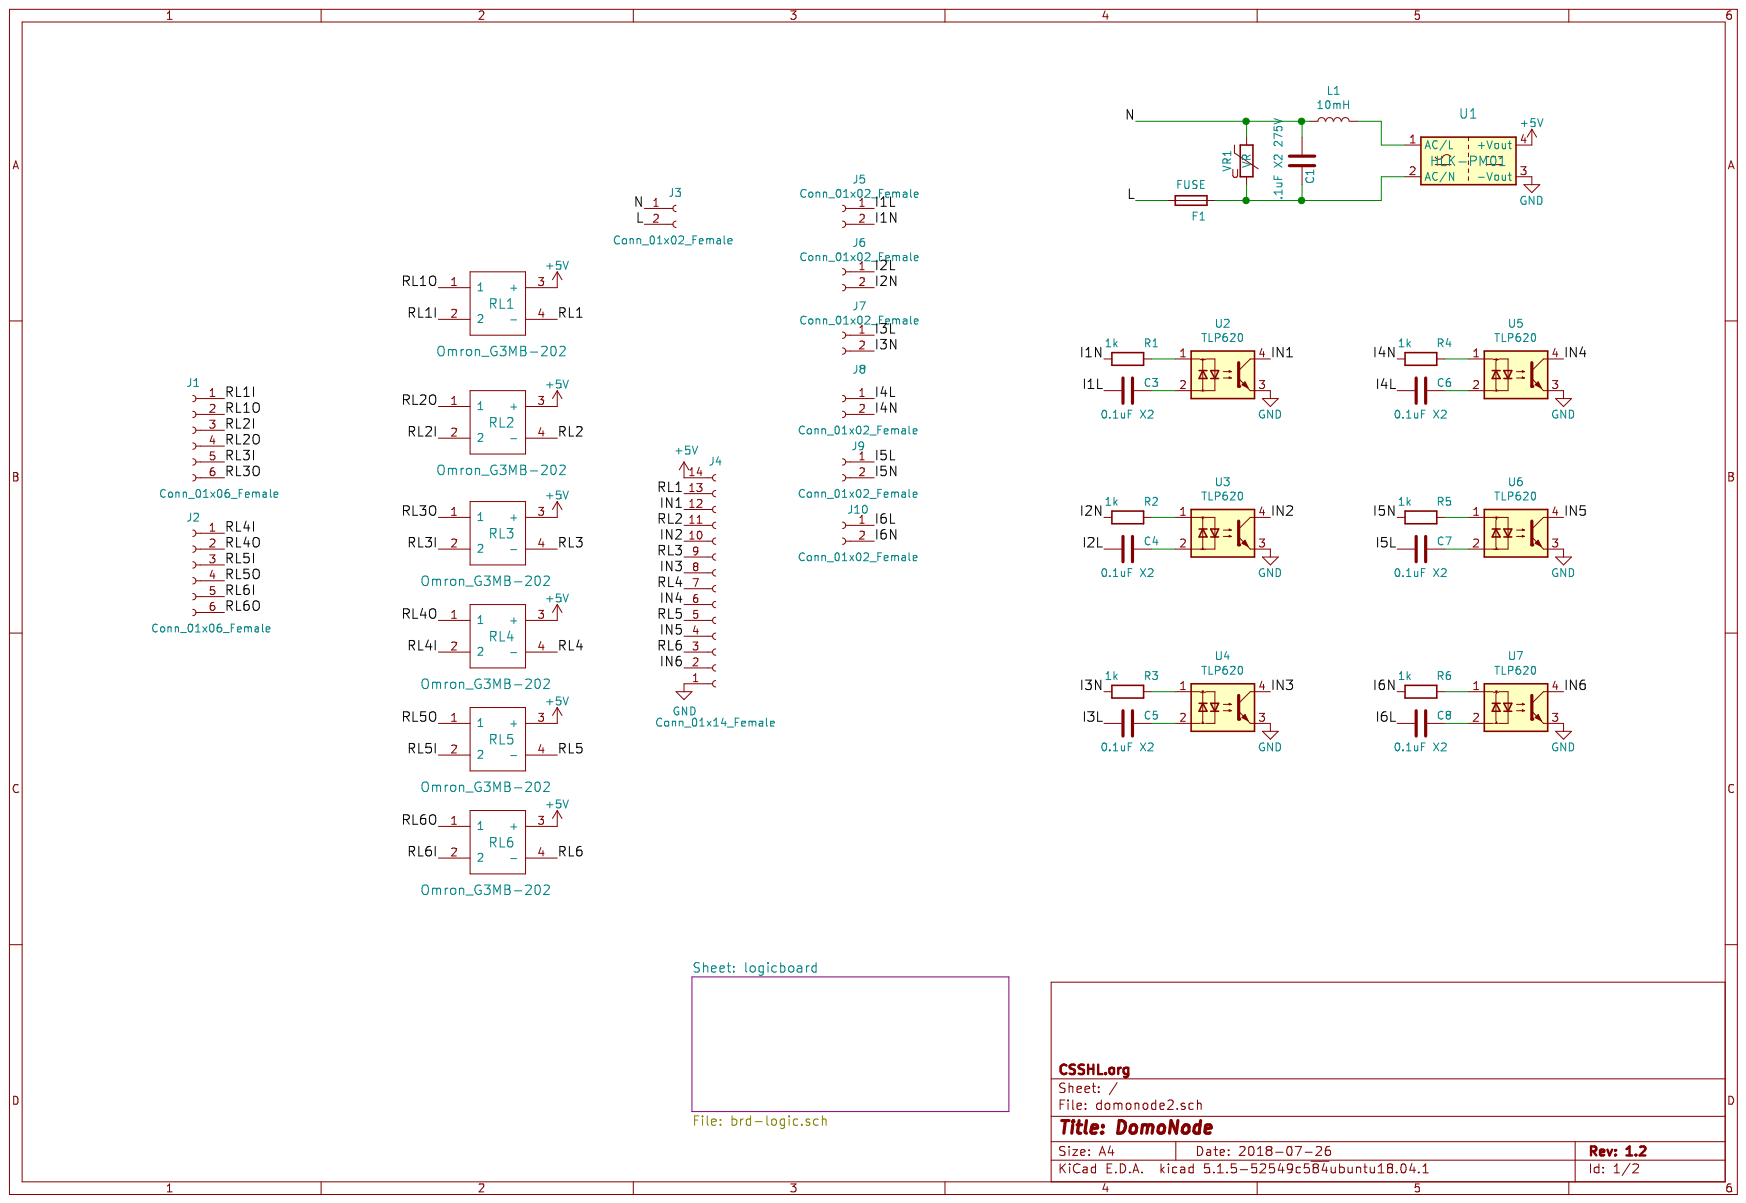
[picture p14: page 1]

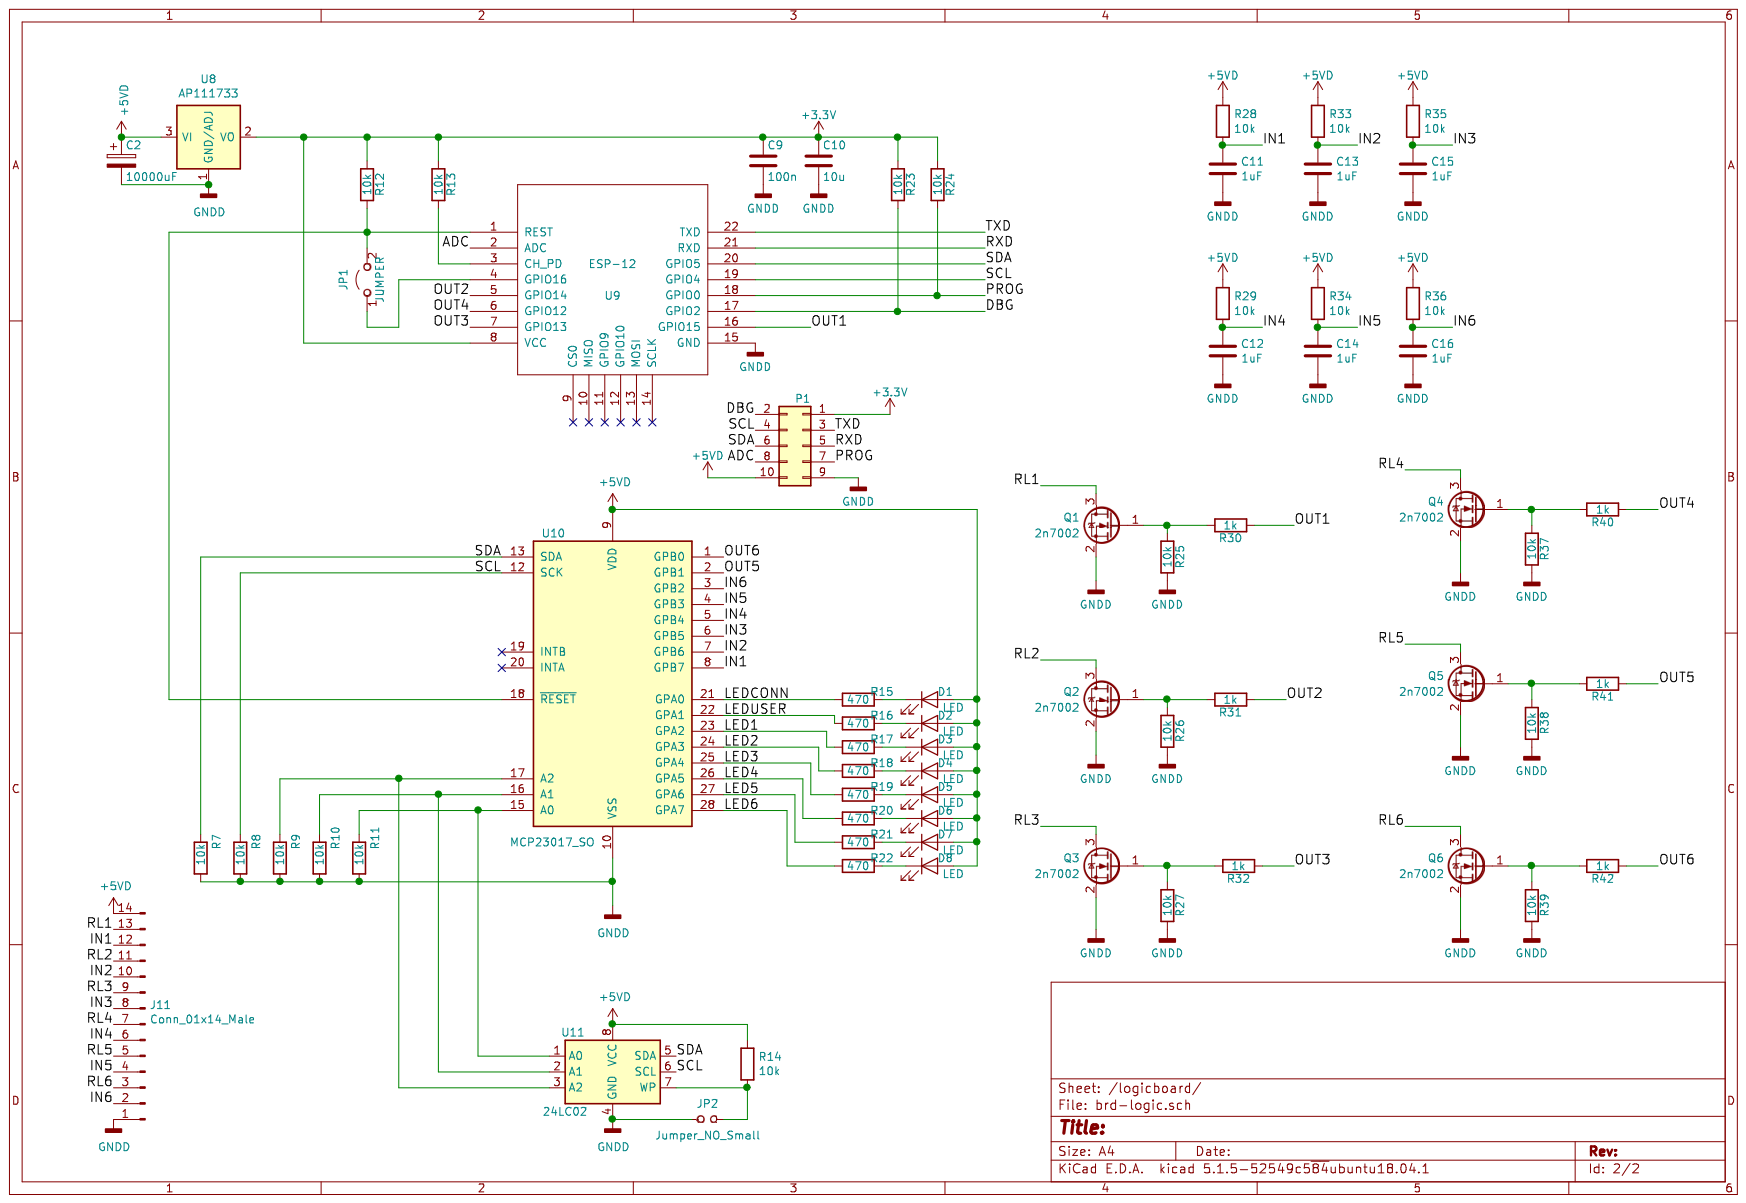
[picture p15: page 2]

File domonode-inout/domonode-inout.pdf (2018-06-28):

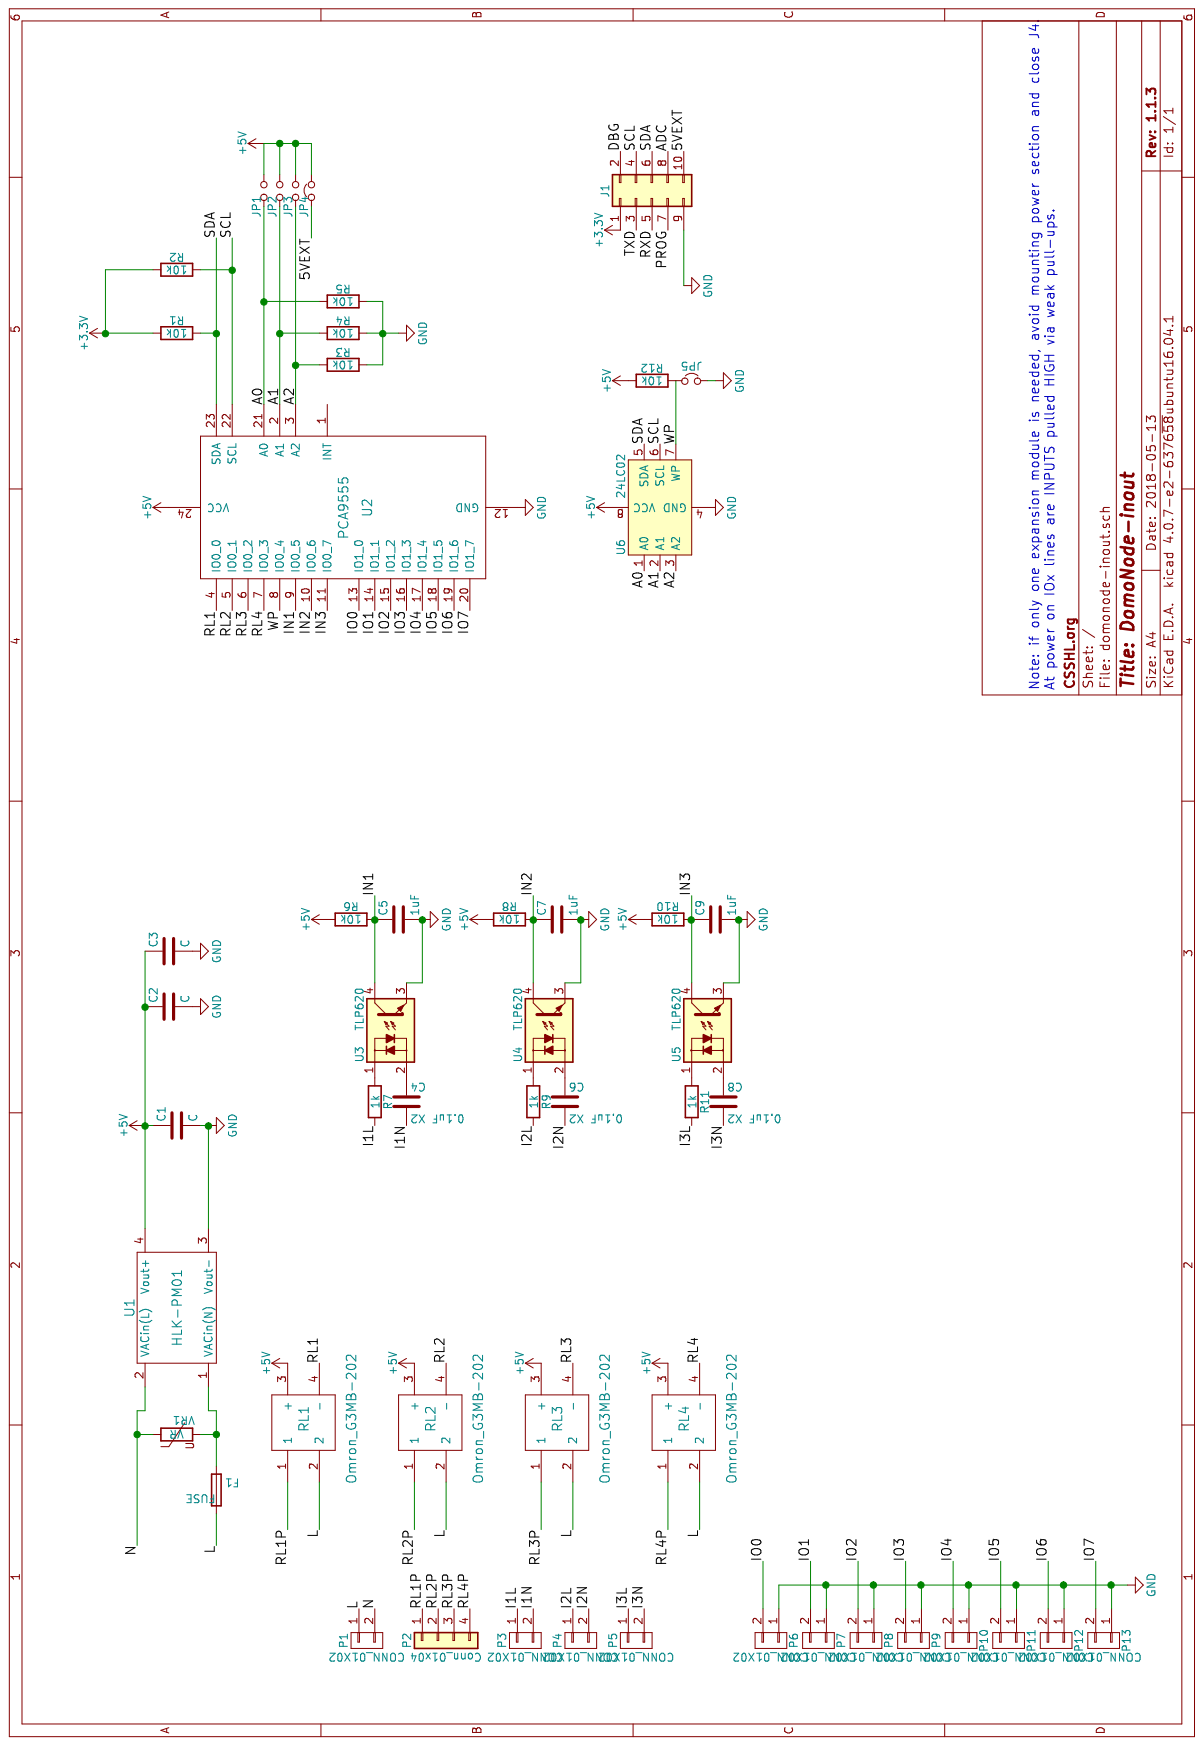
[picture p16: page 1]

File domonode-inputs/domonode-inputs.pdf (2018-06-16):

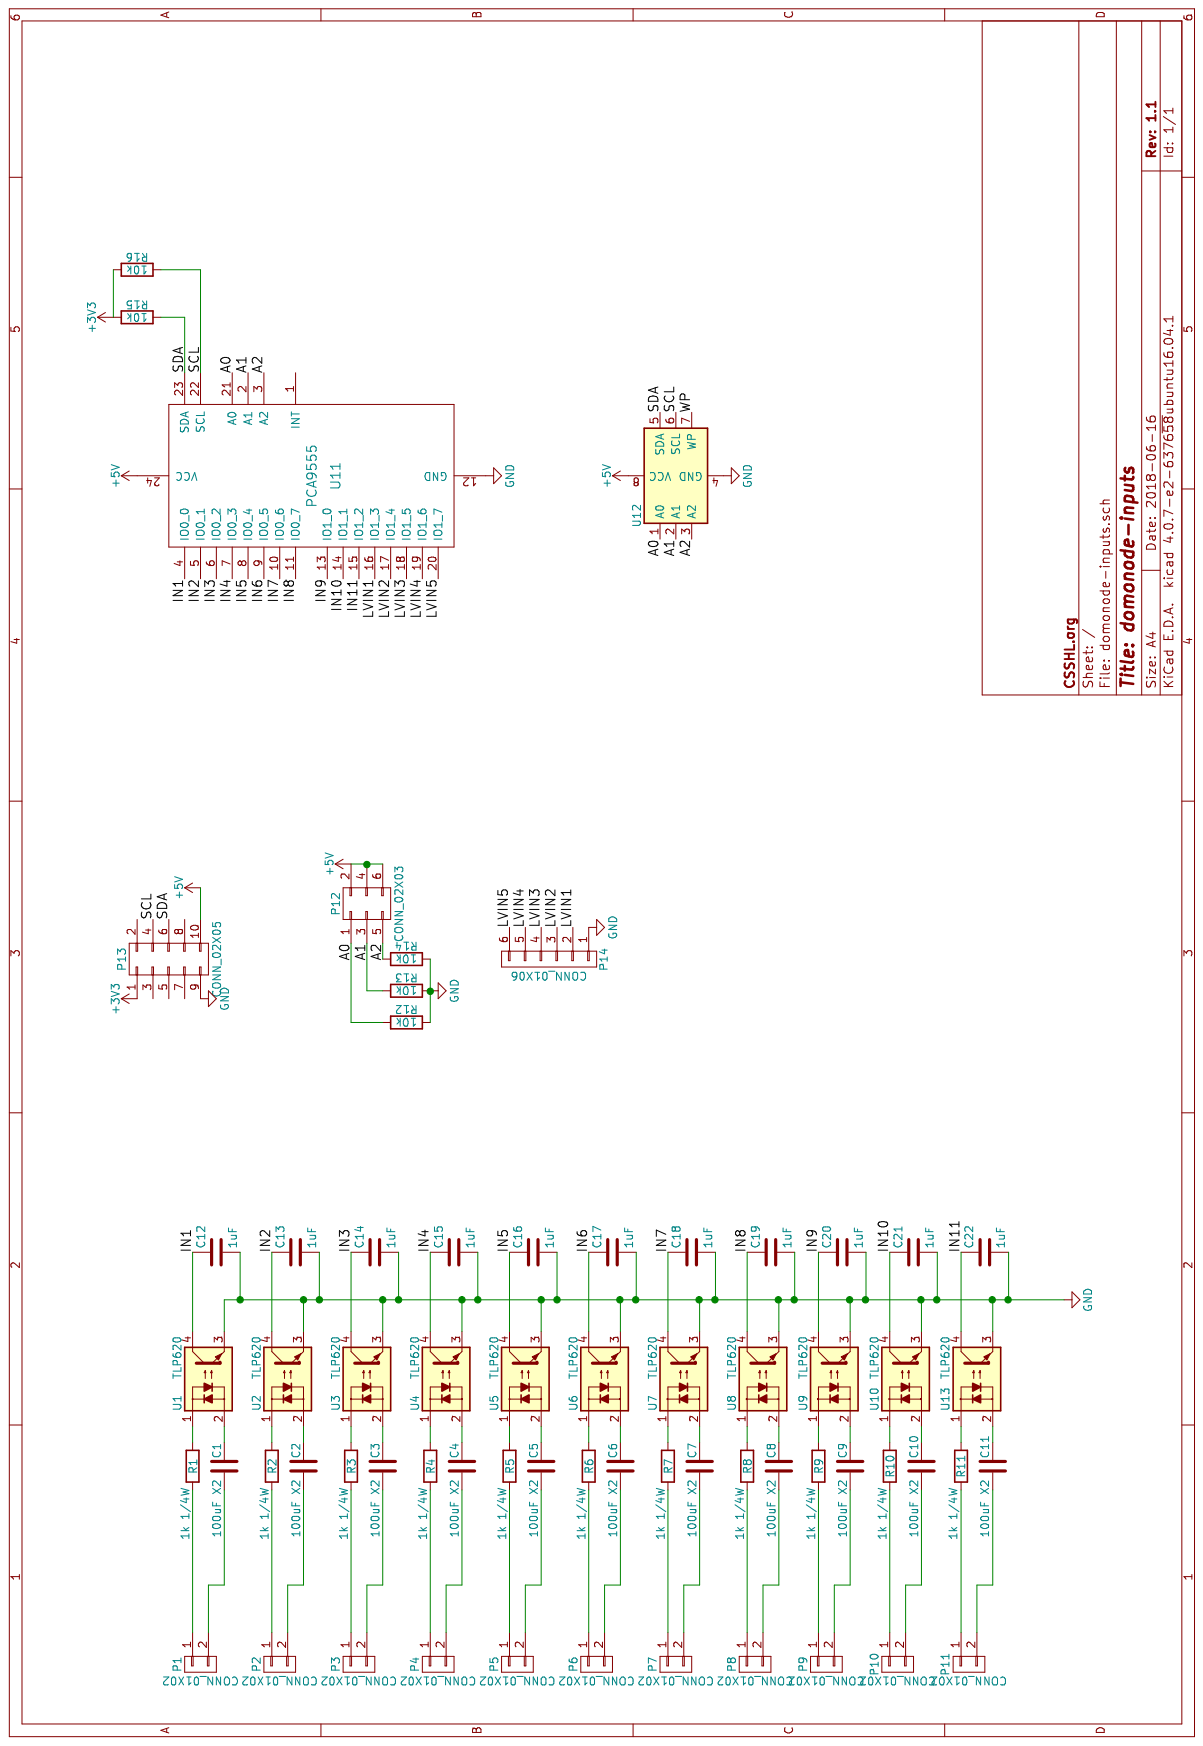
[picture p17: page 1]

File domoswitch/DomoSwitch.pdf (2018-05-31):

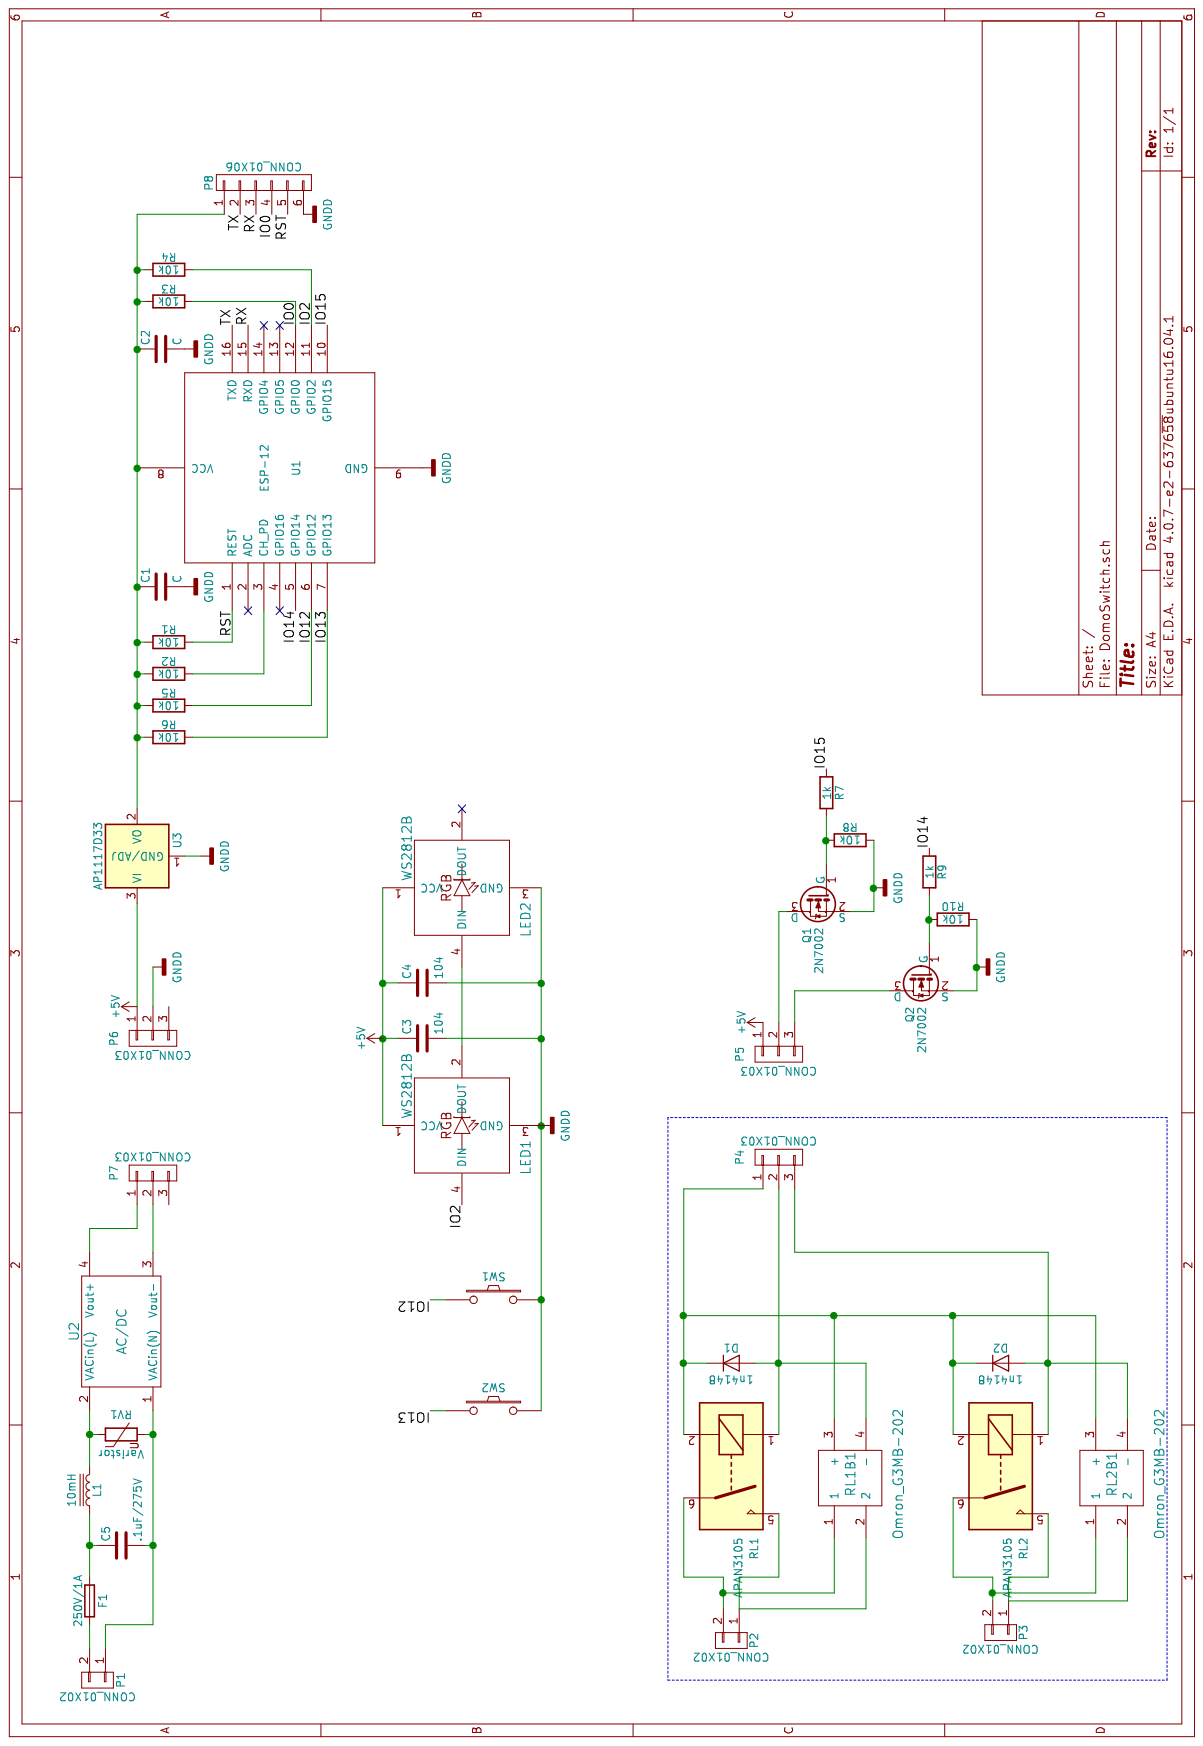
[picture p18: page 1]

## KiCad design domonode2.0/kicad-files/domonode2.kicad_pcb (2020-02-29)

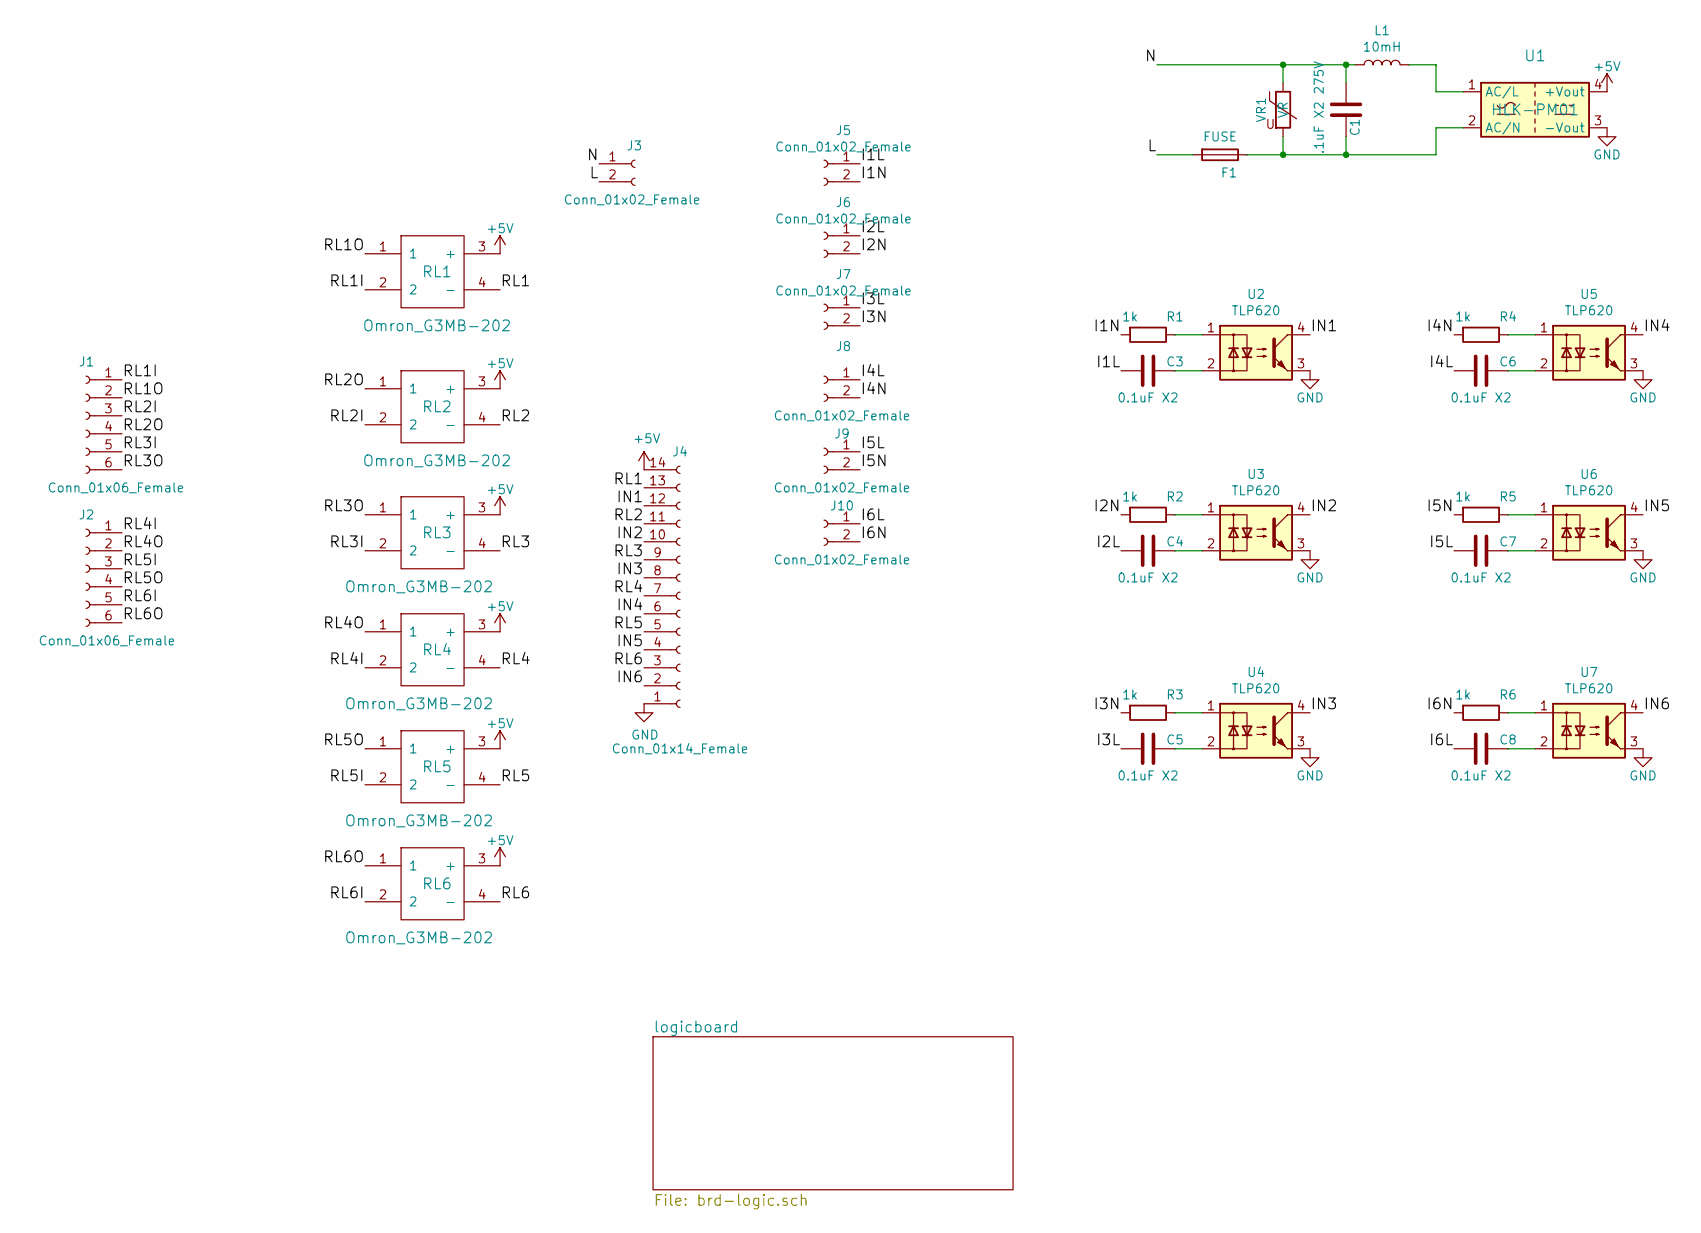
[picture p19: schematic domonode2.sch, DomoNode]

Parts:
C1: .1uF X2 275V; C_Rect_L13.0mm_W6.0mm_P10.00mm_FKS3_FKP3_MKS4
C3, C4, C5, C6, C7, C8: 0.1uF X2; C_Rect_L13.0mm_W6.0mm_P10.00mm_FKS3_FKP3_MKS4
F1: FUSE; Fuseholder5x20_horiz_SemiClosed_Casing10x25mm
J1, J2: Conn_01x06_Female; KF2EDGK-5.08-6
J3: Conn_01x02_Female; KF2EDGK-5.08-2
J4: Conn_01x14_Female; PinSocket_1x14_P2.54mm_Vertical
J5, J6, J7, J8, J9, J10: Conn_01x02_Female; KF2EDGK-3.81-2
L1: 10mH; INDUCTOR_0810
R1, R2, R3, R4, R5, R6: 1k; R_Axial_DIN0411_L9.9mm_D3.6mm_P12.70mm_Horizontal
RL1, RL2, RL3, RL4, RL5, RL6: Omron_G3MB-202; G3MB
U1: HLK-PM01; ACDC-HLK+ND
U2, U3, U4, U5, U6, U7: TLP620; DIP-4_W7.62mm_e_SOT-4
VR1: VR; RV_Disc_D15.5mm_W4.2mm_P7.5mm

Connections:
+5V: J4.14, RL1.3 (+), RL2.3 (+), RL3.3 (+), RL4.3 (+), RL5.3 (+), RL6.3 (+), U1.4 (+Vout)
/I1L: C3.2, J5.1
/I1N: J5.2, R1.2
/I2L: C4.2, J6.1
/I2N: J6.2, R2.2
/I3L: C5.2, J7.1
/I3N: J7.2, R3.2
/I4L: C6.2, J8.1
/I4N: J8.2, R4.2
/I5L: C7.2, J9.1
/I5N: J9.2, R5.2
/I6L: C8.2, J10.1
/I6N: J10.2, R6.2
/IN1: J4.12, U2.4
/IN2: J4.10, U3.4
/IN3: J4.8, U4.4
/IN4: J4.6, U5.4
/IN5: J4.4, U6.4
/IN6: J4.2, U7.4
/L: F1.2, J3.2
/N: C1.1, J3.1, L1.1, VR1.1
/RL1: J4.13, RL1.4 (-)
/RL1I: J1.1, RL1.2
/RL1O: J1.2, RL1.1
/RL2: J4.11, RL2.4 (-)
/RL2I: J1.3, RL2.2
/RL2O: J1.4, RL2.1
/RL3: J4.9, RL3.4 (-)
/RL3I: J1.5, RL3.2
/RL3O: J1.6, RL3.1
/RL4: J4.7, RL4.4 (-)
/RL4I: J2.1, RL4.2
/RL4O: J2.2, RL4.1
/RL5: J4.5, RL5.4 (-)
/RL5I: J2.3, RL5.2
/RL5O: J2.4, RL5.1
/RL6: J4.3, RL6.4 (-)
/RL6I: J2.5, RL6.2
/RL6O: J2.6, RL6.1
GND: J4.1, U1.3 (-Vout), U2.3, U3.3, U4.3, U5.3, U6.3, U7.3
unnamed: C1.2, F1.1, U1.2 (AC/N), VR1.2
unnamed: C3.1, U2.2
unnamed: C4.1, U3.2
unnamed: C5.1, U4.2
unnamed: C6.1, U5.2
unnamed: C7.1, U6.2
unnamed: C8.1, U7.2
unnamed: L1.2, U1.1 (AC/L)
unnamed: R1.1, U2.1
unnamed: R2.1, U3.1
unnamed: R3.1, U4.1
unnamed: R4.1, U5.1
unnamed: R5.1, U6.1
unnamed: R6.1, U7.1

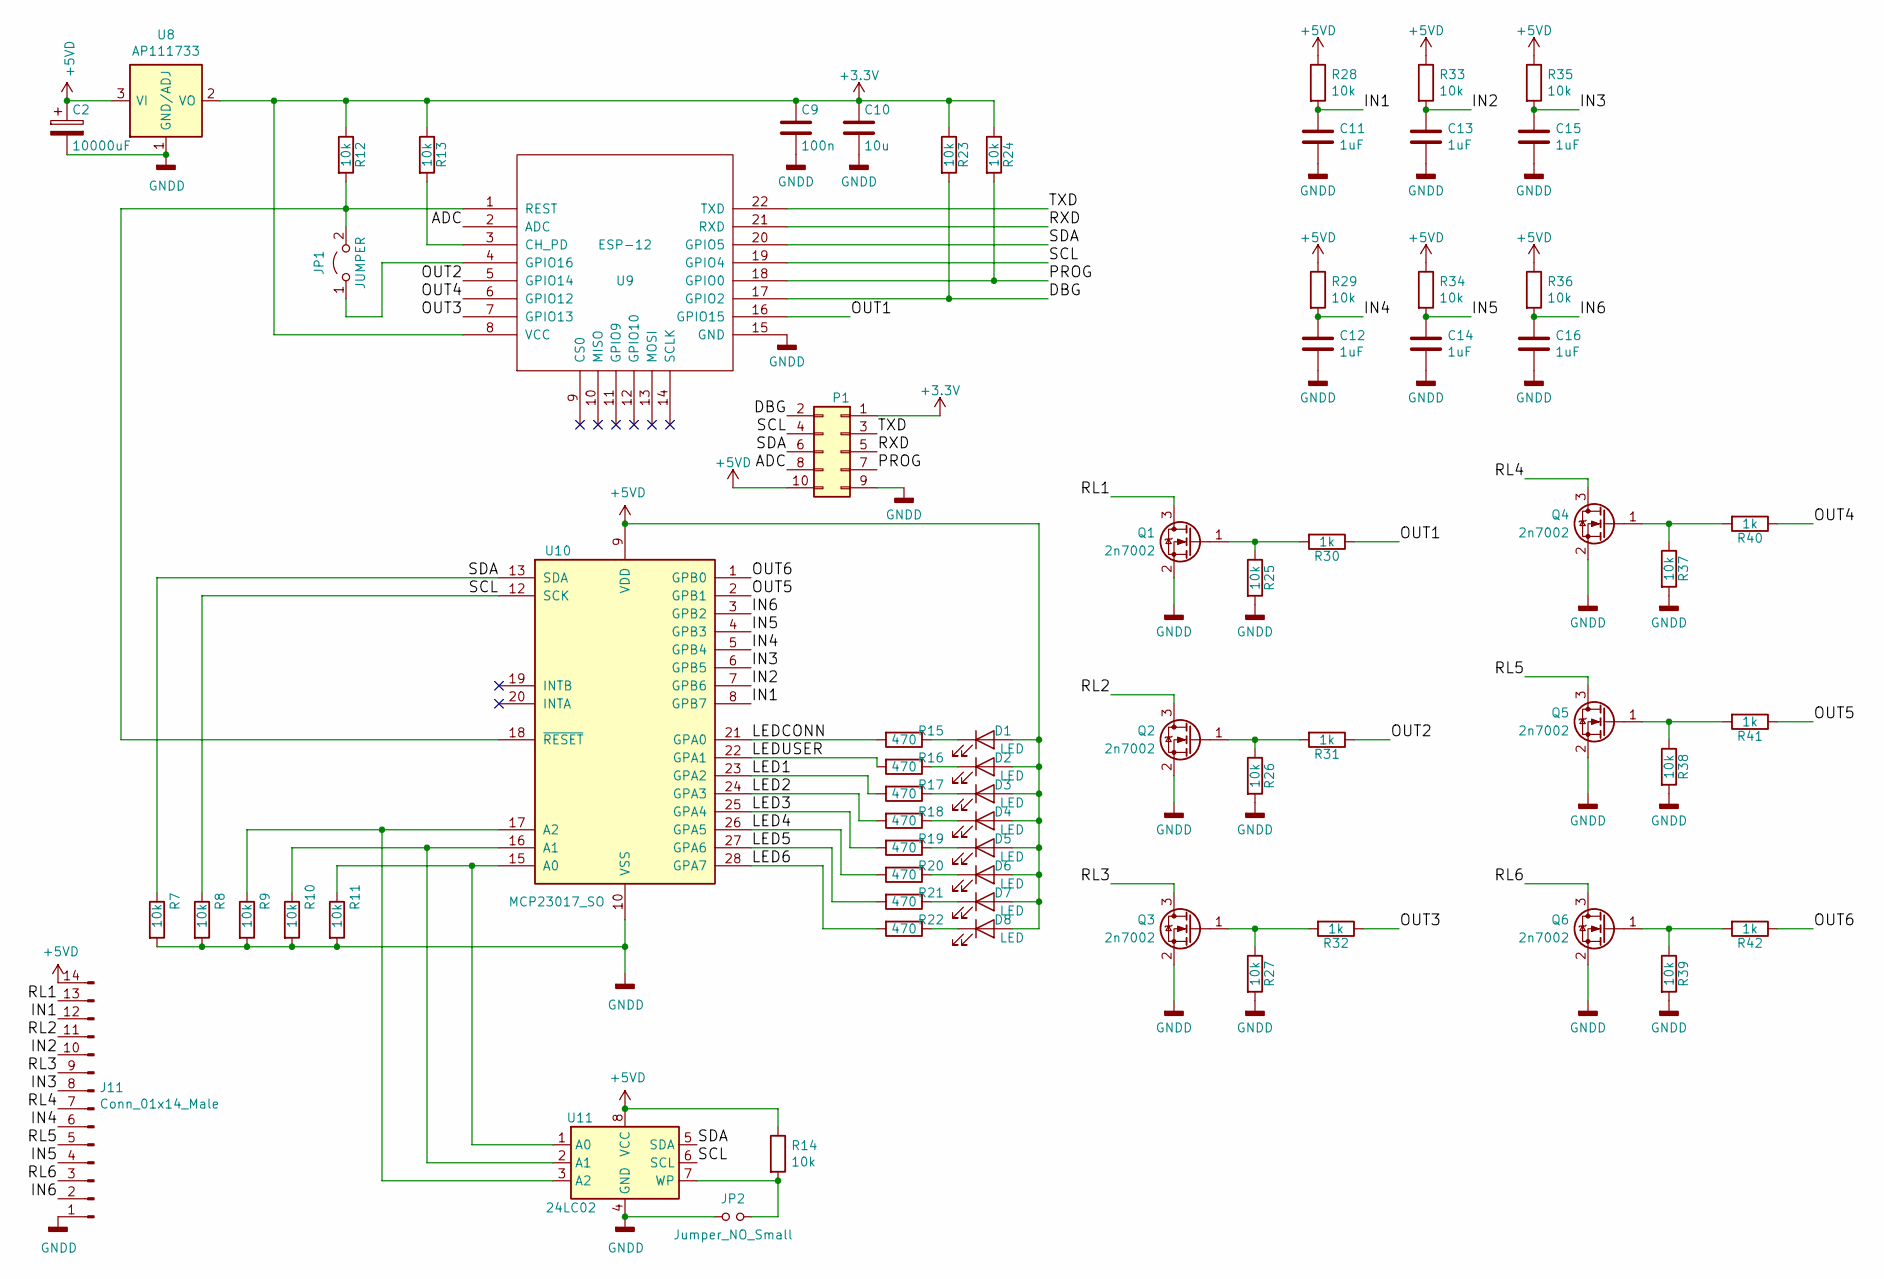
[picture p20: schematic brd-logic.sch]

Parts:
C2: 10000uF; CP_Elec_10x10
C9: 100n; C_0805_2012Metric
C10: 10u; C_0805_2012Metric
C11, C12, C13, C14, C15, C16: 1uF; C_0805_2012Metric
D1, D2, D3, D4, D5, D6, D7, D8: LED; LED_D3.0mm
J11: Conn_01x14_Male; PinSocket_1x14_P2.54mm_Vertical
JP1: JUMPER; PinSocket_1x02_P2.54mm_Vertical
JP2: Jumper_NO_Small; PinSocket_1x02_P2.54mm_Vertical
P1: CONN_2x5; Multicomp_MC9A12-1034_2x05_P2.54mm_Vertical
Q1, Q2, Q3, Q4, Q5, Q6: 2n7002; SOT-23
R7, R8, R9, R10, R11, R12, R13, R14, R23, R24, R25, R26, R27, R28, R29, R33, R34, R35, R36, R37, R38, R39: 10k; R_0805_2012Metric
R15, R16, R17, R18, R19, R20, R21, R22: 470; R_0805_2012Metric
R30, R31, R32, R40, R41, R42: 1k; R_0805_2012Metric
U8: AP111733; SOT-223-3_TabPin2
U9: ESP-12; ESP-12E
U10: MCP23017_SO; SOIC-28W_7.5x17.9mm_P1.27mm
U11: 24LC02; SOIC-8_3.9x4.9mm_P1.27mm

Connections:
+3V3: C9.1, C10.1, P1.1, R12.1, R13.1, R23.1, R24.1, U8.2 (VO), U9.8 (VCC)
+5VD: C2.1, D1.2 (A), D2.2 (A), D3.2 (A), D4.2 (A), D5.2 (A), D6.2 (A), D7.2 (A), D8.2 (A), J11.14, P1.10, R14.1, R28.1, R29.1, R33.1, R34.1, R35.1, R36.1, U8.3 (VI), U10.9 (VDD), U11.8 (VCC)
/logicboard/ADC: P1.8, U9.2 (ADC)
/logicboard/DBG: P1.2, R23.2, U9.17 (GPIO2)
/logicboard/IN1: C11.1, J11.12, R28.2, U10.8 (GPB7)
/logicboard/IN2: C13.1, J11.10, R33.2, U10.7 (GPB6)
/logicboard/IN3: C15.1, J11.8, R35.2, U10.6 (GPB5)
/logicboard/IN4: C12.1, J11.6, R29.2, U10.5 (GPB4)
/logicboard/IN5: C14.1, J11.4, R34.2, U10.4 (GPB3)
/logicboard/IN6: C16.1, J11.2, R36.2, U10.3 (GPB2)
/logicboard/LED1: R17.2, U10.23 (GPA2)
/logicboard/LED2: R18.2, U10.24 (GPA3)
/logicboard/LED3: R19.2, U10.25 (GPA4)
/logicboard/LED4: R20.2, U10.26 (GPA5)
/logicboard/LED5: R21.2, U10.27 (GPA6)
/logicboard/LED6: R22.2, U10.28 (GPA7)
/logicboard/LEDCONN: R15.2, U10.21 (GPA0)
/logicboard/LEDUSER: R16.2, U10.22 (GPA1)
/logicboard/OUT1: R30.1, U9.16 (GPIO15)
/logicboard/OUT2: R31.1, U9.5 (GPIO14)
/logicboard/OUT3: R32.1, U9.7 (GPIO13)
/logicboard/OUT4: R40.1, U9.6 (GPIO12)
/logicboard/OUT5: R41.1, U10.2 (GPB1)
/logicboard/OUT6: R42.1, U10.1 (GPB0)
/logicboard/PROG: P1.7, R24.2, U9.18 (GPIO0)
/logicboard/RL1: J11.13, Q1.3 (D)
/logicboard/RL2: J11.11, Q2.3 (D)
/logicboard/RL3: J11.9, Q3.3 (D)
/logicboard/RL4: J11.7, Q4.3 (D)
/logicboard/RL5: J11.5, Q5.3 (D)
/logicboard/RL6: J11.3, Q6.3 (D)
/logicboard/RXD: P1.5, U9.21 (RXD)
/logicboard/SCL: P1.4, R8.1, U9.19 (GPIO4), U10.12 (SCK), U11.6 (SCL)
/logicboard/SDA: P1.6, R7.1, U9.20 (GPIO5), U10.13 (SDA), U11.5 (SDA)
/logicboard/TXD: P1.3, U9.22 (TXD)
GNDD: C2.2, C9.2, C10.2, C11.2, C12.2, C13.2, C14.2, C15.2, C16.2, J11.1, JP2.1, P1.9, Q1.2 (S), Q2.2 (S), Q3.2 (S), Q4.2 (S), Q5.2 (S), Q6.2 (S), R7.2, R8.2, R9.2, R10.2, R11.2, R25.2, R26.2, R27.2, R37.2, R38.2, R39.2, U8.1 (GND/ADJ), U9.15 (GND), U10.10 (VSS), U11.4 (GND)
unnamed: D1.1 (K), R15.1
unnamed: D2.1 (K), R16.1
unnamed: D3.1 (K), R17.1
unnamed: D4.1 (K), R18.1
unnamed: D5.1 (K), R19.1
unnamed: D6.1 (K), R20.1
unnamed: D7.1 (K), R21.1
unnamed: D8.1 (K), R22.1
unnamed: JP1.1 (A), U9.4 (GPIO16)
unnamed: JP1.2 (B), R12.2, U9.1 (REST), U10.18 (~RESET~)
unnamed: JP2.2, R14.2, U11.7 (WP)
unnamed: Q1.1 (G), R25.1, R30.2
unnamed: Q2.1 (G), R26.1, R31.2
unnamed: Q3.1 (G), R27.1, R32.2
unnamed: Q4.1 (G), R37.1, R40.2
unnamed: Q5.1 (G), R38.1, R41.2
unnamed: Q6.1 (G), R39.1, R42.2
unnamed: R9.1, U10.17 (A2), U11.3 (A2)
unnamed: R10.1, U10.16 (A1), U11.2 (A1)
unnamed: R11.1, U10.15 (A0), U11.1 (A0)
unnamed: R13.2, U9.3 (CH_PD)

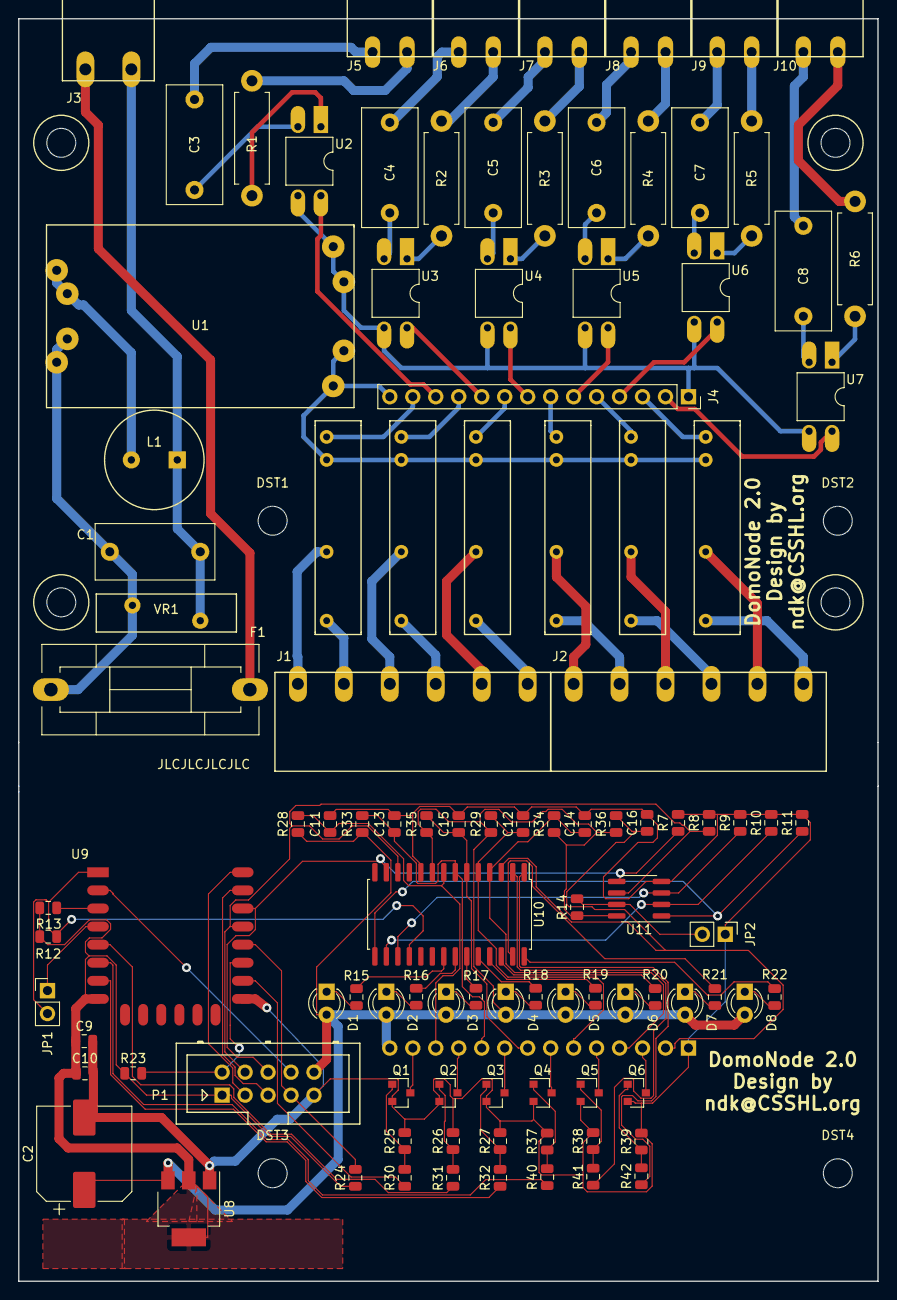
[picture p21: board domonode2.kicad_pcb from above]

Board: 2 copper layers, 95.0 x 139.6 mm, 111 parts (1 on the bottom side), 111 nets.

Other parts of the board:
BOX: Enclosure_DIN_6p_nomargin
DST1, DST2, DST3, DST4: MountingHole_3.2mm_M3

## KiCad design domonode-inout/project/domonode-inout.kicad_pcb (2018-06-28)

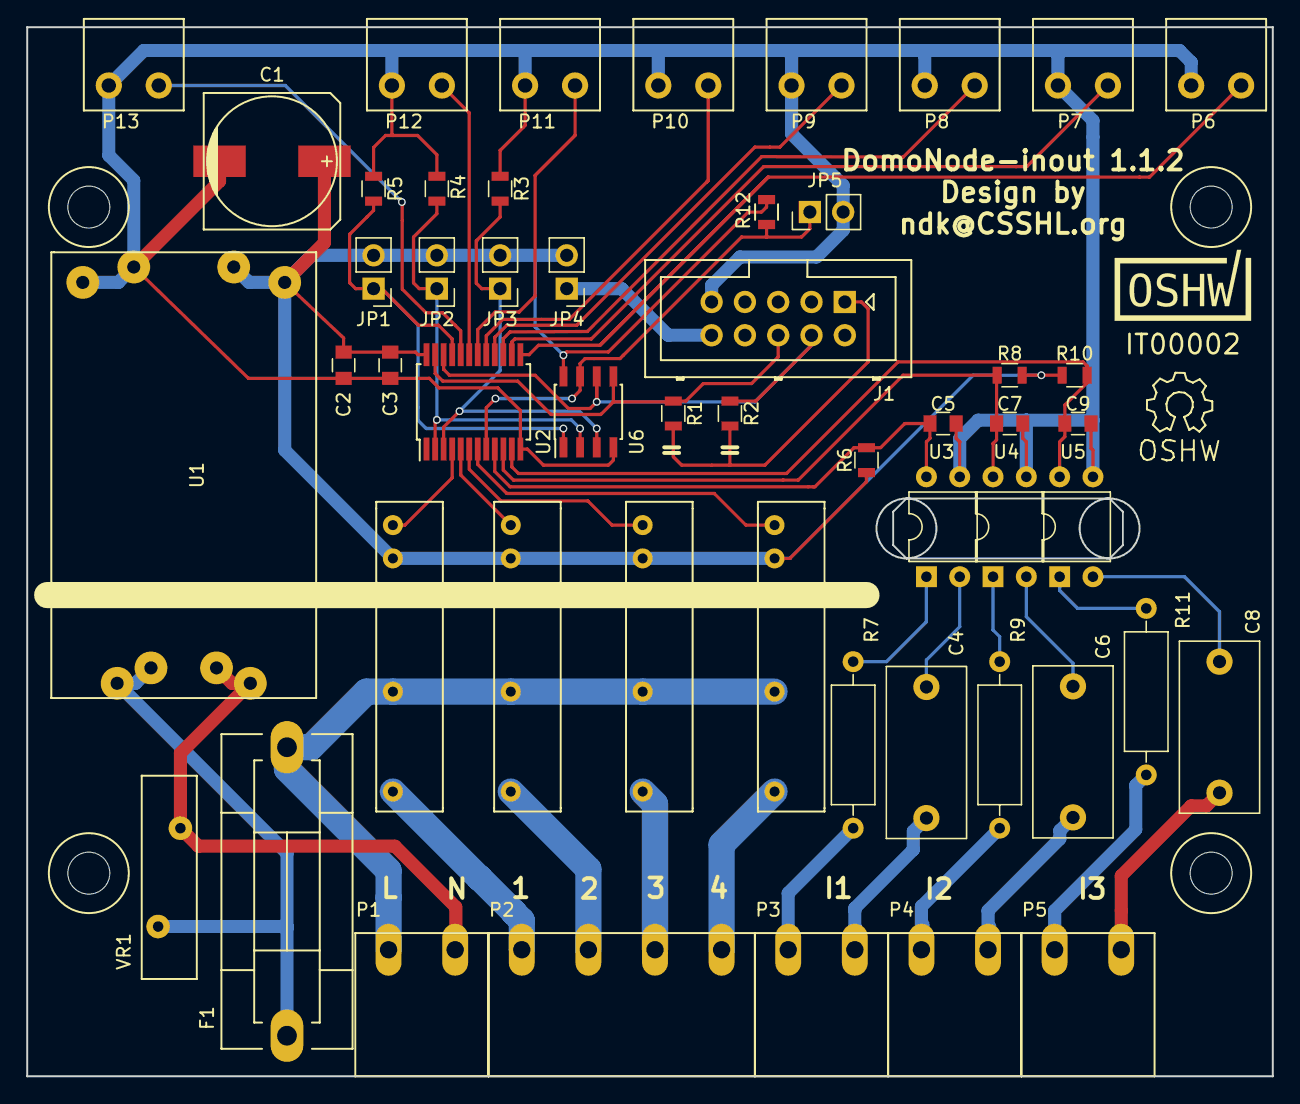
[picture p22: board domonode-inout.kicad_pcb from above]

Board: 2 copper layers, 95.0 x 80.0 mm, 54 parts (0 on the bottom side), 44 nets.

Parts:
BOX: Enclosure_DIN_6p_nomargin
C1: C; c_elec_10x10
C2, C3: C; C_0805
C4, C6, C8: 0.1uF X2; C_Rect_L13.0mm_W6.0mm_P10.00mm_FKS3_FKP3_MKS4
C5, C7, C9: 1uF; C_0805
F1: FUSE; Fuseholder5x20_horiz_SemiClosed_Casing10x25mm
J1: CONN_2x5; Multicomp_MC9A12-1034_2x05x2.54mm_Straight
JP1, JP2, JP3: Jumper_NO_Small; Pin_Header_Straight_1x02_Pitch2.54mm
JP4, JP5: Jumper_NC_Small; Pin_Header_Straight_1x02_Pitch2.54mm
OSHW_Mono_0.25_Scale: IT00002; OSHW_Mono_0.25_Scale
P1, P3, P4, P5: CONN_01X02; KF2EDGK-5.08-2
P2: Conn_01x04; KF2EDGK-5.08-4
P6, P7, P8, P9, P10, P11, P12, P13: CONN_01X02; ScrewTerm_2x3.81_bigpads
R1, R2, R3, R4, R5, R6, R8, R10, R12: 10k; R_0805
R7, R9, R11: 1k; R_Axial_DIN0309_L9.0mm_D3.2mm_P12.70mm_Horizontal
RL1, RL2, RL3, RL4: Omron_G3MB-202; G3MB
U1: HLK-PM01; ACDC-HLK+ND
U2: PCA9555; SSOP-24_5.3x8.2mm_Pitch0.65mm
U3, U4, U5: TLP620; DIP-4_W7.62mm
U6: 24LC02; SOIC-8_3.9x4.9mm_Pitch1.27mm
VR1: VR; RV_Disc_D15.5_W4.2_P7.5

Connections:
+3V3: J1.1, R1.1, R2.1
+5V: C1.1, C2.1, C3.1, JP1.2, JP2.2, JP3.2, JP4.2, R6.1, R8.1, R10.1, R12.1, RL1.3, RL2.3, RL3.3, RL4.3, U1.4, U2.24, U6.8
/5VEXT: J1.10, JP4.1
/A0: JP1.1, R5.1, U2.21, U6.1
/A1: JP2.1, R4.1, U2.2, U6.2
/A2: JP3.1, R3.1, U2.3, U6.3
/I1L: P3.1, R7.2
/I1N: C4.2, P3.2
/I2L: P4.1, R9.2
/I2N: C6.2, P4.2
/I3L: P5.1, R11.2
/I3N: C8.2, P5.2
/IN1: C5.1, R6.2, U2.9, U3.4
/IN2: C7.1, R8.2, U2.10, U4.4
/IN3: C9.1, R10.2, U2.11, U5.4
/IO0: P6.2, U2.13
/IO1: P7.2, U2.14
/IO2: P8.2, U2.15
/IO3: P9.2, U2.16
/IO4: P10.2, U2.17
/IO5: P11.2, U2.18
/IO6: P12.2, U2.19
/IO7: P13.2, U2.20
/L: F1.2, P1.1, RL1.2, RL2.2, RL3.2, RL4.2
/N: P1.2, U1.2, VR1.1
/RL1: RL1.4, U2.4
/RL1P: P2.1, RL1.1
/RL2: RL2.4, U2.5
/RL2P: P2.2, RL2.1
/RL3: RL3.4, U2.6
/RL3P: P2.3, RL3.1
/RL4: RL4.4, U2.7
/RL4P: P2.4, RL4.1
/SCL: J1.4, R2.2, U2.22, U6.6
/SDA: J1.6, R1.2, U2.23, U6.5
/WP: JP5.1, R12.2, U2.8, U6.7
GND: C1.2, C2.2, C3.2, C5.2, C7.2, C9.2, J1.9, JP5.2, P6.1, P7.1, P8.1, P9.1, P10.1, P11.1, P12.1, P13.1, R3.2, R4.2, R5.2, U1.3, U2.12, U3.3, U4.3, U5.3, U6.4
unnamed: C4.1, U3.2
unnamed: C6.1, U4.2
unnamed: C8.1, U5.2
unnamed: F1.1, U1.1, VR1.2
unnamed: R7.1, U3.1
unnamed: R9.1, U4.1
unnamed: R11.1, U5.1

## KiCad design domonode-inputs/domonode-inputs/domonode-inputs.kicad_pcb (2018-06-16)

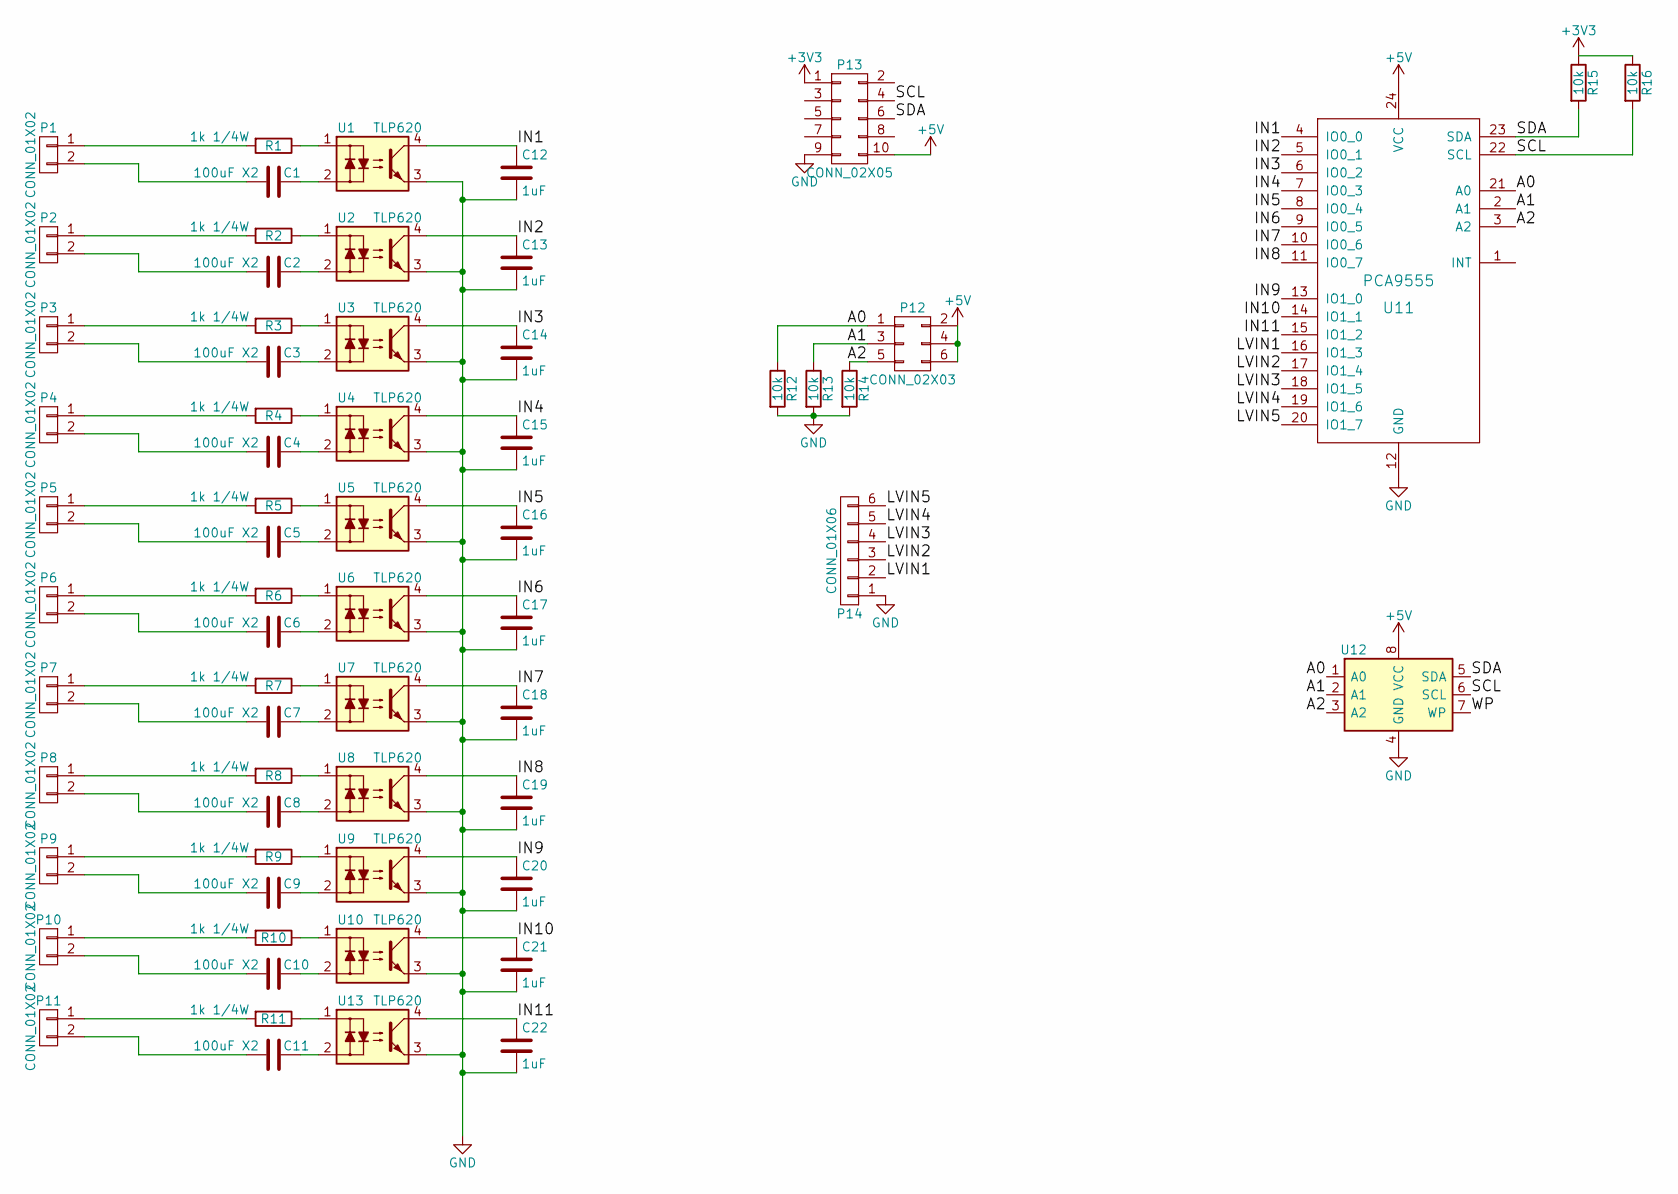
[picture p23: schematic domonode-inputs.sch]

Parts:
C1, C2, C3, C4, C5, C6, C7, C8, C9, C10, C11: 100uF X2; C_Rect_L13.0mm_W6.0mm_P10.00mm_FKS3_FKP3_MKS4
C12, C13, C14, C15, C16, C17, C18, C19, C20, C21, C22: 1uF; C_0805
P1, P2, P3, P4, P5, P6, P7, P8, P9, P10, P11: CONN_01X02; KF2EDGK-5.08-2
P12: CONN_02X03; Pin_Header_Straight_2x03_Pitch2.54mm
P13: CONN_02X05; Multicomp_MC9A12-1034_2x05x2.54mm_Straight
P14: CONN_01X06; Pin_Header_Straight_1x06
R1, R2, R3, R4, R5, R6, R7, R8, R9, R10, R11: 1k 1/4W; R_Axial_DIN0309_L9.0mm_D3.2mm_P12.70mm_Horizontal
R12, R13, R14, R15, R16: 10k; R_0805
U1, U2, U3, U4, U5, U6, U7, U8, U9, U10, U13: TLP620; DIP-4_W7.62mm_e_SOT-4
U11: PCA9555; SSOP-24_5.3x8.2mm_Pitch0.65mm
U12: 24LC02; SOIC-8_3.9x4.9mm_Pitch1.27mm

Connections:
+3V3: P13.1, R15.1, R16.1
+5V: P12.2, P12.4, P12.6, P13.10, U11.24 (VCC), U12.8 (VCC)
/A0: P12.1, R12.1, U11.21 (A0), U12.1 (A0)
/A1: P12.3, R13.1, U11.2 (A1), U12.2 (A1)
/A2: P12.5, R14.1, U11.3 (A2), U12.3 (A2)
/IN1: C12.1, U1.4, U11.4 (IO0_0)
/IN2: C13.1, U2.4, U11.5 (IO0_1)
/IN3: C14.1, U3.4, U11.6 (IO0_2)
/IN4: C15.1, U4.4, U11.7 (IO0_3)
/IN5: C16.1, U5.4, U11.8 (IO0_4)
/IN6: C17.1, U6.4, U11.9 (IO0_5)
/IN7: C18.1, U7.4, U11.10 (IO0_6)
/IN8: C19.1, U8.4, U11.11 (IO0_7)
/IN9: C20.1, U9.4, U11.13 (IO1_0)
/IN10: C21.1, U10.4, U11.14 (IO1_1)
/IN11: C22.1, U11.15 (IO1_2), U13.4
/LVIN1: P14.2, U11.16 (IO1_3)
/LVIN2: P14.3, U11.17 (IO1_4)
/LVIN3: P14.4, U11.18 (IO1_5)
/LVIN4: P14.5, U11.19 (IO1_6)
/LVIN5: P14.6, U11.20 (IO1_7)
/SCL: P13.4, R16.2, U11.22 (SCL), U12.6 (SCL)
/SDA: P13.6, R15.2, U11.23 (SDA), U12.5 (SDA)
GND: C12.2, C13.2, C14.2, C15.2, C16.2, C17.2, C18.2, C19.2, C20.2, C21.2, C22.2, P13.9, P14.1, R12.2, R13.2, R14.2, U1.3, U2.3, U3.3, U4.3, U5.3, U6.3, U7.3, U8.3, U9.3, U10.3, U11.12 (GND), U12.4 (GND), U13.3
unnamed: C1.1, U1.2
unnamed: C1.2, P1.2
unnamed: C2.1, U2.2
unnamed: C2.2, P2.2
unnamed: C3.1, U3.2
unnamed: C3.2, P3.2
unnamed: C4.1, U4.2
unnamed: C4.2, P4.2
unnamed: C5.1, U5.2
unnamed: C5.2, P5.2
unnamed: C6.1, U6.2
unnamed: C6.2, P6.2
unnamed: C7.1, U7.2
unnamed: C7.2, P7.2
unnamed: C8.1, U8.2
unnamed: C8.2, P8.2
unnamed: C9.1, U9.2
unnamed: C9.2, P9.2
unnamed: C10.1, U10.2
unnamed: C10.2, P10.2
unnamed: C11.1, U13.2
unnamed: C11.2, P11.2
unnamed: P1.1, R1.2
unnamed: P2.1, R2.2
unnamed: P3.1, R3.2
unnamed: P4.1, R4.2
unnamed: P5.1, R5.2
unnamed: P6.1, R6.2
unnamed: P7.1, R7.2
unnamed: P8.1, R8.2
unnamed: P9.1, R9.2
unnamed: P10.1, R10.2
unnamed: P11.1, R11.2
unnamed: R1.1, U1.1
unnamed: R2.1, U2.1
unnamed: R3.1, U3.1
unnamed: R4.1, U4.1
unnamed: R5.1, U5.1
unnamed: R6.1, U6.1
unnamed: R7.1, U7.1
unnamed: R8.1, U8.1
unnamed: R9.1, U9.1
unnamed: R10.1, U10.1
unnamed: R11.1, U13.1

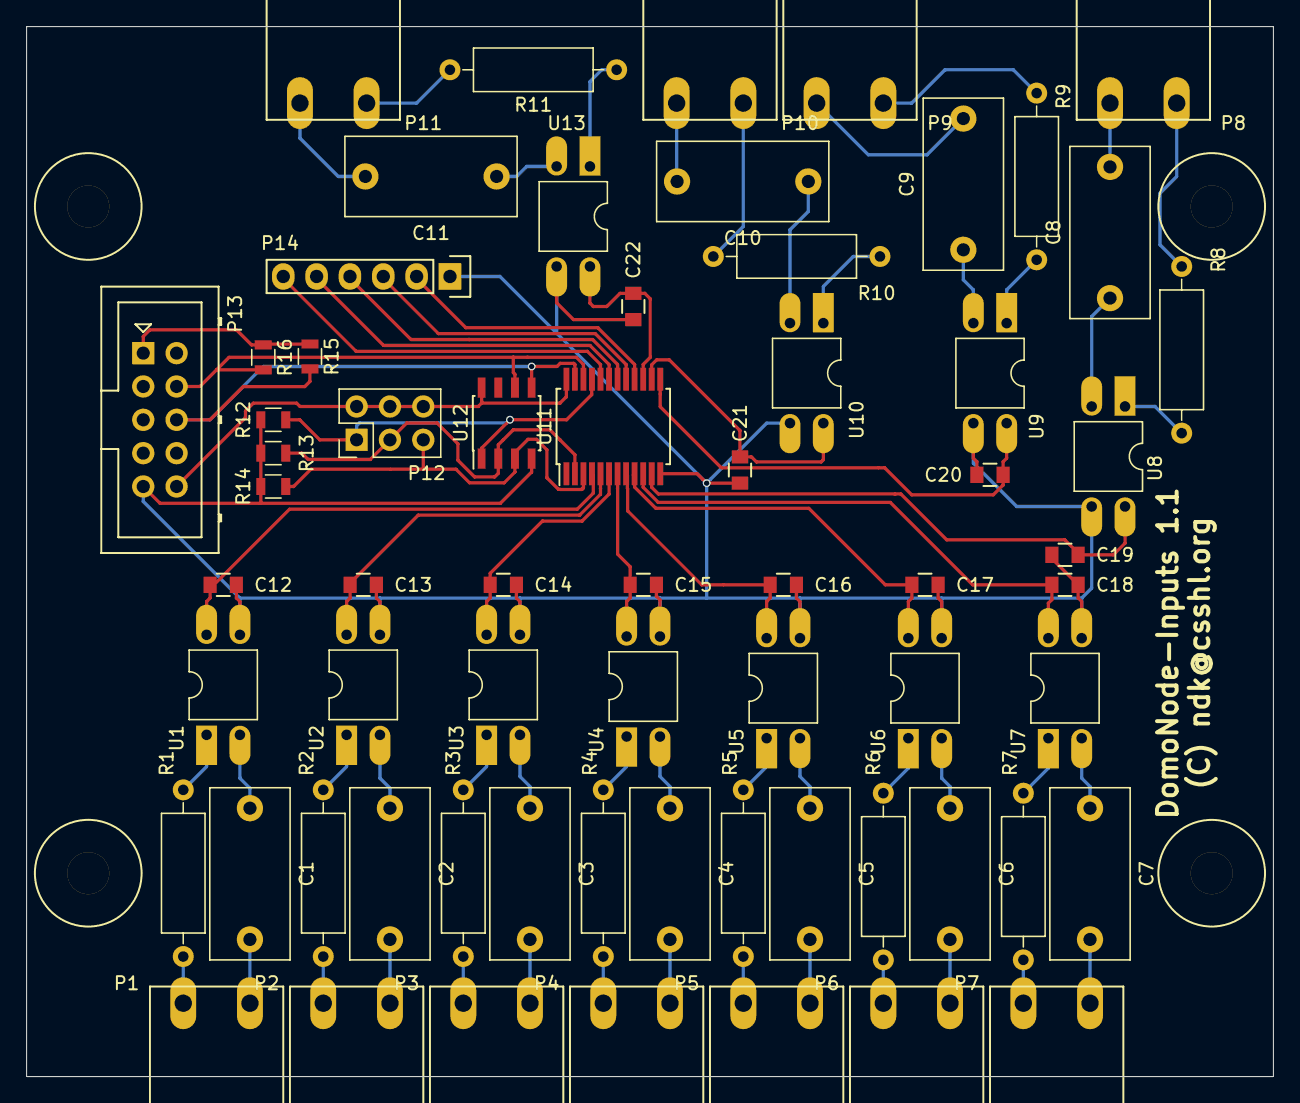
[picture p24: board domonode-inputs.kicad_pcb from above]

Board: 2 copper layers, 95.0 x 80.0 mm, 66 parts (0 on the bottom side), 68 nets.

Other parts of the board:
BOX: Enclosure_DIN_6p

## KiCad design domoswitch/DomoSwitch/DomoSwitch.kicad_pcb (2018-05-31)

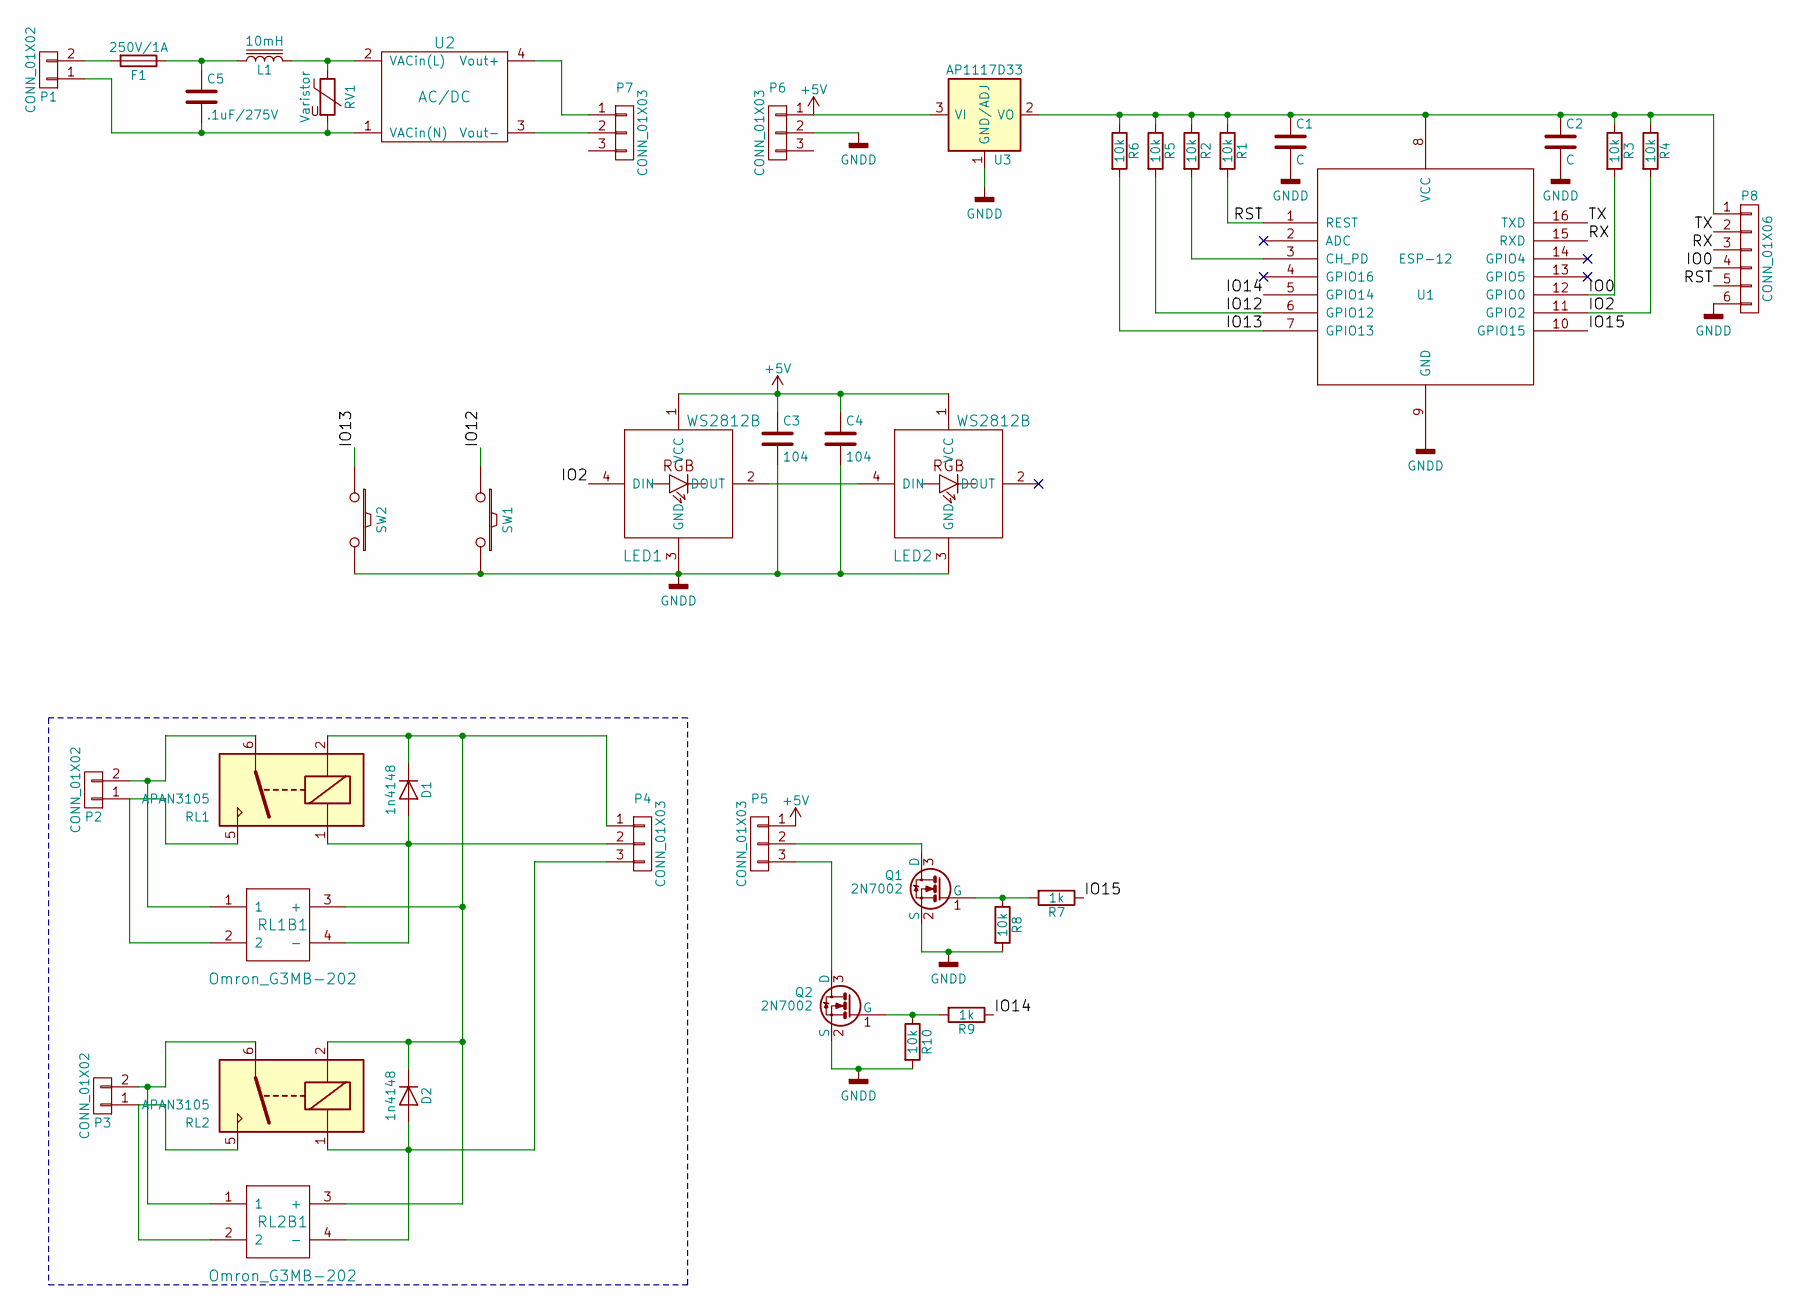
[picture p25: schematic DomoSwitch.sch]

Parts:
C1, C2: C; C_0805
C3, C4: 104; C_0805
C5: .1uF/275V; C_Rect_L13.0mm_W6.0mm_P10.00mm_FKS3_FKP3_MKS4
D1, D2: 1n4148; Diode_DO-41_SOD81_Vertical_KathodeUp
F1: 250V/1A; Fuse_SMD2920
L1: 10mH; CDRH127
LED1, LED2: WS2812B; ws2812b
P1, P2, P3: CONN_01X02; TerminalBlock_bornier-2_P5.08mm
P4, P5, P6, P7: CONN_01X03; Socket_Strip_Straight_1x03_Pitch2.54mm
P8: CONN_01X06; Socket_Strip_Straight_1x06
Q1, Q2: 2N7002; SOT-23
R1, R2, R3, R4, R5, R6, R8, R10: 10k; R_0805
R7, R9: 1k; R_0805
RL1, RL2: APAN3105; APAN31xx
RL1B1, RL2B1: Omron_G3MB-202; G3MB
RV1: Varistor; RV_Disc_D15.5_W4.2_P7.5
SW1, SW2: SW_PUSH; SW_SPST_FSMSM
U1: ESP-12; ESP-12-SMD
U2: AC/DC; HLK-PM01
U3: AP1117D33; SOT-223-3Lead_TabPin2

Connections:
+5V: C3.1, C4.1, LED1.1 (VCC), LED2.1 (VCC), P5.1, P6.1, U3.3 (VI)
/IO0: P8.4, R3.2, U1.12 (GPIO0)
/IO2: LED1.4 (DIN), R4.2, U1.11 (GPIO2)
/IO12: R5.2, SW1.1, U1.6 (GPIO12)
/IO13: R6.2, SW2.1, U1.7 (GPIO13)
/IO14: R9.1, U1.5 (GPIO14)
/IO15: R7.1, U1.10 (GPIO15)
/RST: P8.5, R1.2, U1.1 (REST)
/RX: P8.3, U1.15 (RXD)
/TX: P8.2, U1.16 (TXD)
GNDD: C1.2, C2.2, C3.2, C4.2, LED1.3 (GND), LED2.3 (GND), P6.2, P8.6, Q1.2 (S), Q2.2 (S), R8.2, R10.2, SW1.2, SW2.2, U1.9 (GND), U3.1 (GND/ADJ)
unnamed: C1.1, C2.1, P8.1, R1.1, R2.1, R3.1, R4.1, R5.1, R6.1, U1.8 (VCC), U3.2 (VO)
unnamed: C5.1, F1.1, L1.1
unnamed: C5.2, P1.1, RV1.2, U2.1 (VACin(N))
unnamed: D1.1 (K), D2.1 (K), P4.1, RL1.2, RL1B1.3 (+), RL2.2, RL2B1.3 (+)
unnamed: D1.2 (A), P4.2, RL1.1, RL1B1.4 (-)
unnamed: D2.2 (A), P4.3, RL2.1, RL2B1.4 (-)
unnamed: F1.2, P1.2
unnamed: L1.2, RV1.1, U2.2 (VACin(L))
unnamed: LED1.2 (DOUT), LED2.4 (DIN)
unnamed: P2.1, RL1.5, RL1B1.2
unnamed: P2.2, RL1.6, RL1B1.1
unnamed: P3.1, RL2.5, RL2B1.2
unnamed: P3.2, RL2.6, RL2B1.1
unnamed: P5.2, Q1.3 (D)
unnamed: P5.3, Q2.3 (D)
unnamed: P7.1, U2.4 (Vout+)
unnamed: P7.2, U2.3 (Vout-)
unnamed: Q1.1 (G), R7.2, R8.1
unnamed: Q2.1 (G), R9.2, R10.1
unnamed: R2.2, U1.3 (CH_PD)

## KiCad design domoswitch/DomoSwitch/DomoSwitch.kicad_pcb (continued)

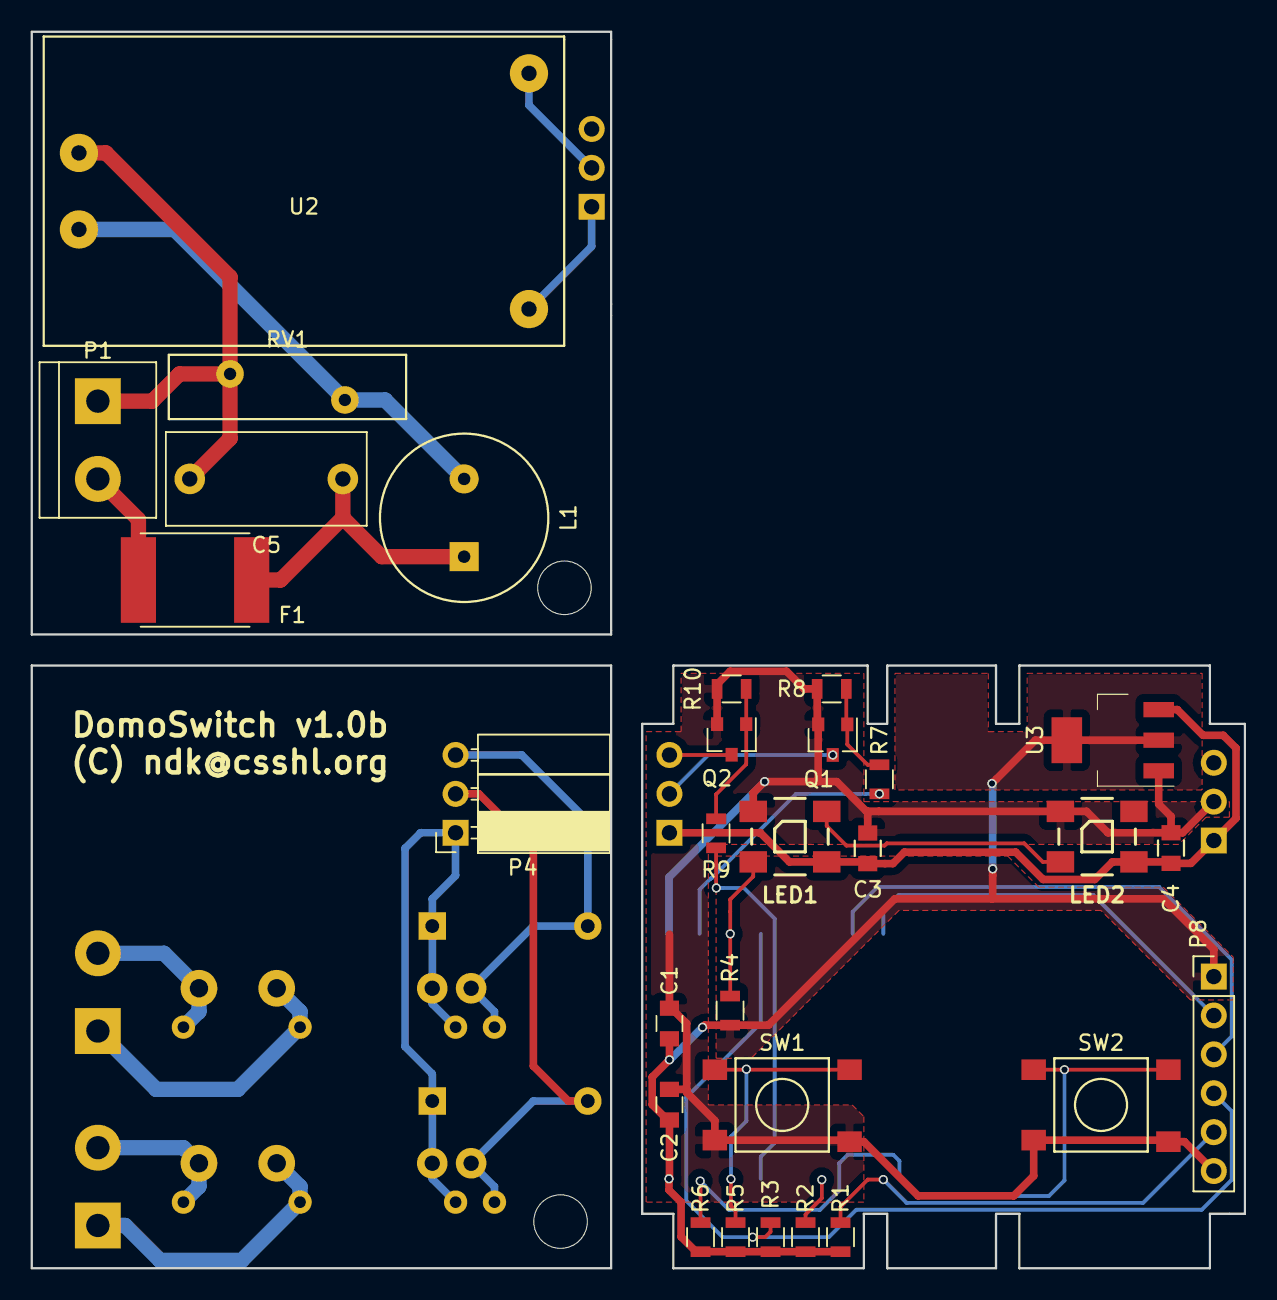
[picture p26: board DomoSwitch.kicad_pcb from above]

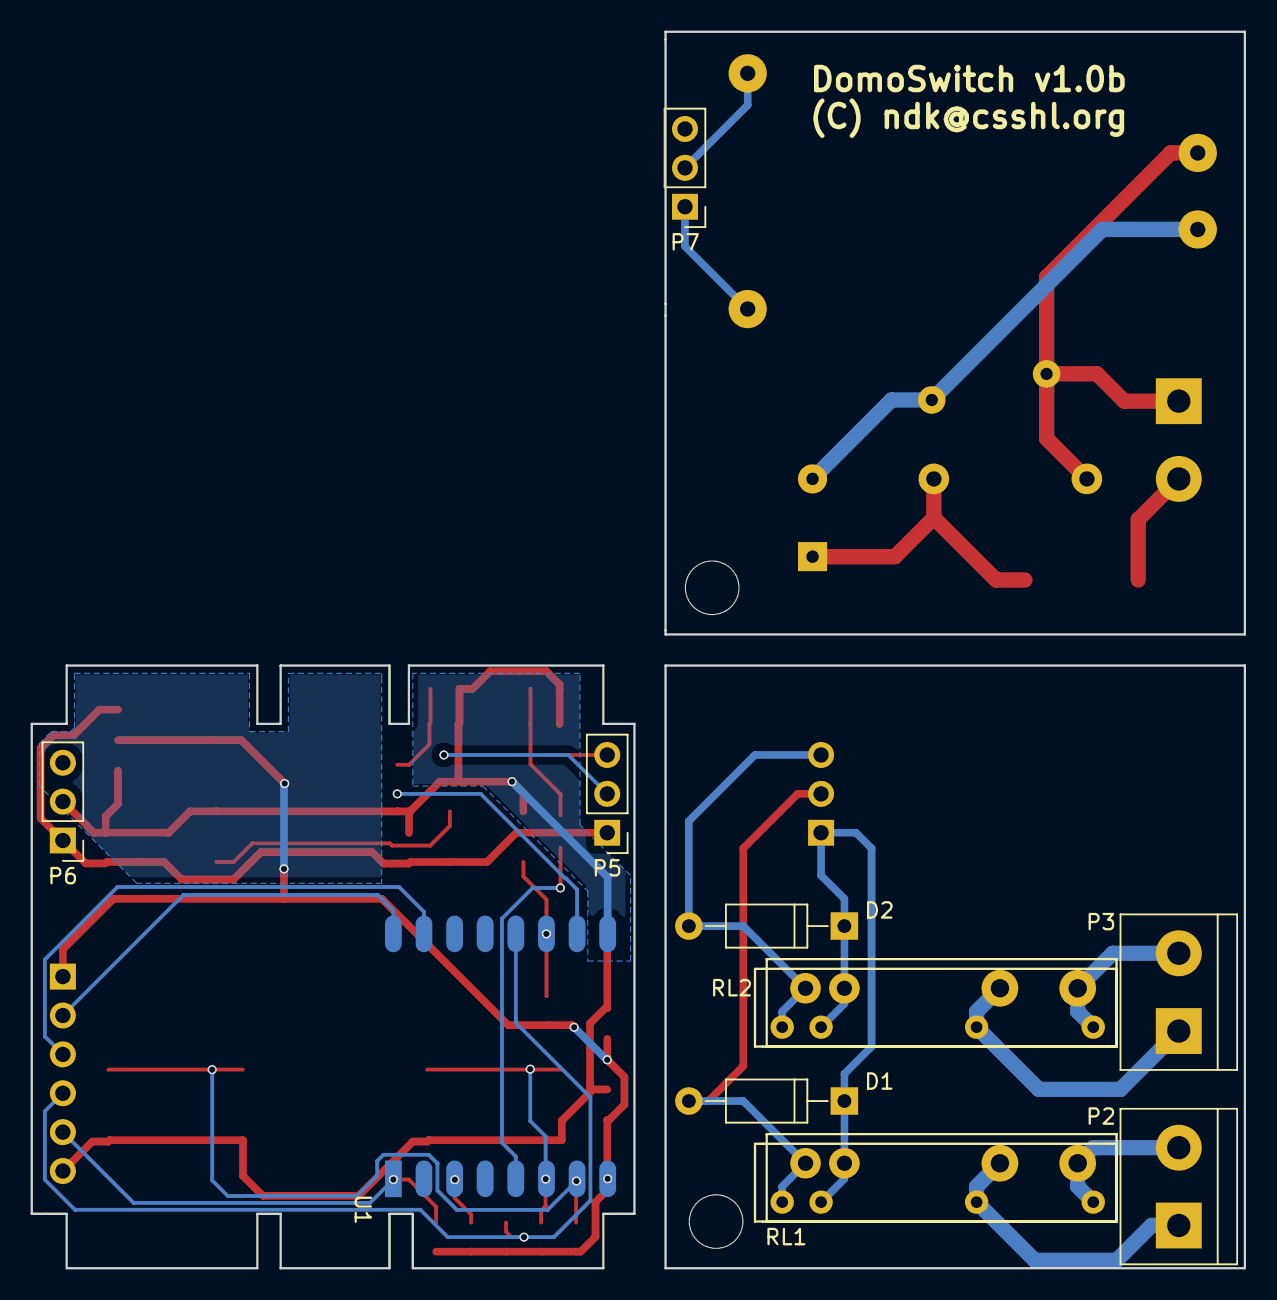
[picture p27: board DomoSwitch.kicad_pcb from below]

Board: 2 copper layers, 79.2 x 80.8 mm, 43 parts (12 on the bottom side), 31 nets.

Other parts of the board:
H1, H5: MountingHole_3-5mm

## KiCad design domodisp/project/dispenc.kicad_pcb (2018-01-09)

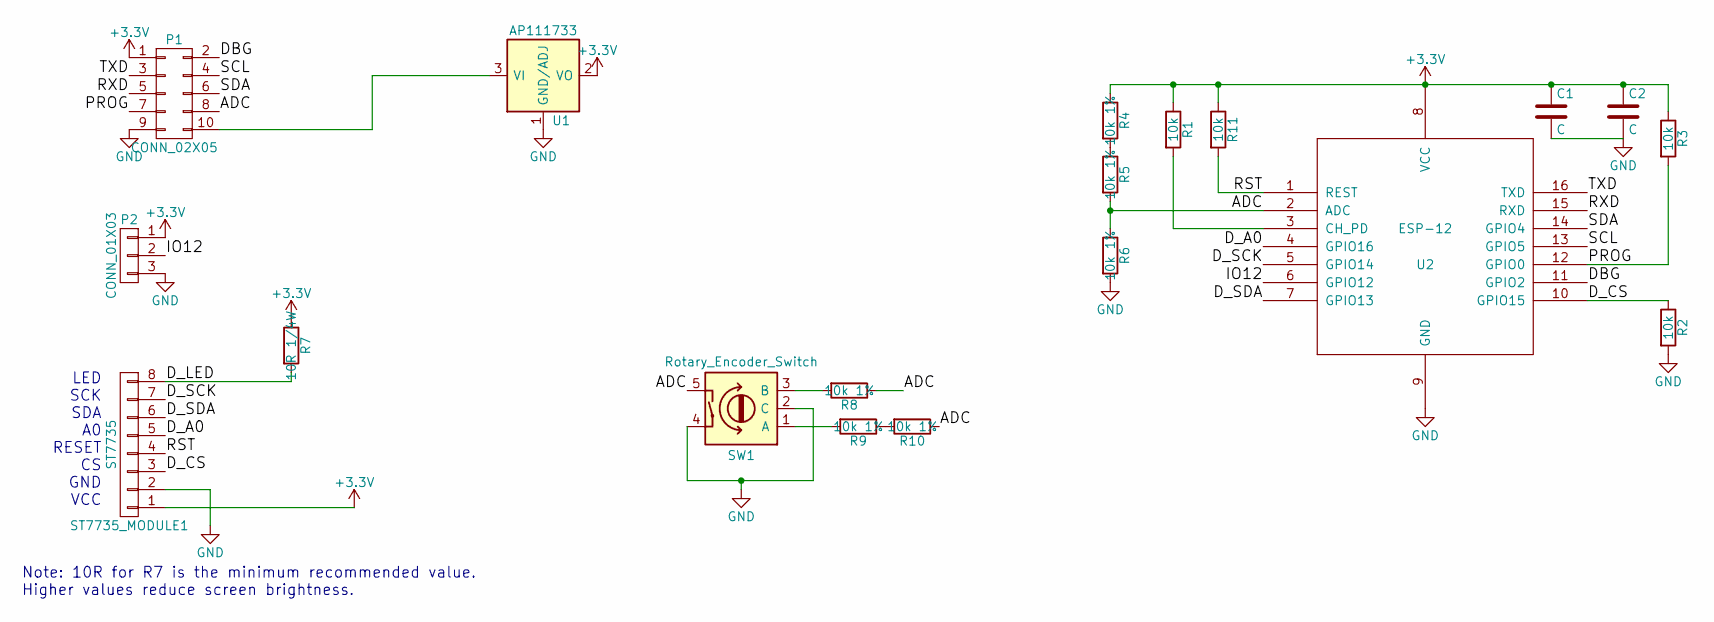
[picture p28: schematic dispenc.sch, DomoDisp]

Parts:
C1, C2: C; C_0805
P1: CONN_02X05; Multicomp_MC9A12-1034_2x05x2.54mm_Straight
P2: CONN_01X03; Pin_Header_Straight_1x03_Pitch2.54mm
R1, R2, R3, R11: 10k; R_0805
R4, R5, R6, R8, R9, R10: 10k 1%; R_0805
R7: 10R 1/4W; R_Axial_DIN0309_L9.0mm_D3.2mm_P12.70mm_Horizontal
ST7735_MODULE1: ST7735; ST7735_module
SW1: Rotary_Encoder_Switch; rotary-encoder
U1: AP111733; SOT-223
U2: ESP-12

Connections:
+3V3: C1.1, C2.1, P1.1, P2.1, R1.1, R3.1, R4.1, R7.1, R11.1, ST7735_MODULE1.1, U1.2 (VO), U1.4 (VO), U2.8 (VCC); also elsewhere on the board
+5V: P1.10, U1.3 (VI)
/ADC: P1.8, R5.2, R6.1, R8.1, R10.1, SW1.5, U2.2 (ADC)
/DBG: P1.2, U2.11 (GPIO2); also elsewhere on the board
/D_A0: ST7735_MODULE1.5, U2.4 (GPIO16)
/D_CS: R2.1, ST7735_MODULE1.3, U2.10 (GPIO15)
/D_LED: R7.2, ST7735_MODULE1.8
/D_SCK: ST7735_MODULE1.7, U2.5 (GPIO14)
/D_SDA: ST7735_MODULE1.6, U2.7 (GPIO13)
/IO12: P2.2, U2.6 (GPIO12)
/PROG: P1.7, R3.2, U2.12 (GPIO0)
/RST: R11.2, ST7735_MODULE1.4, U2.1 (REST)
/RXD: P1.5, U2.15 (RXD)
/SCL: P1.4, U2.13 (GPIO5)
/SDA: P1.6, U2.14 (GPIO4)
/TXD: P1.3, U2.16 (TXD)
GND: C1.2, C2.2, P1.9, P2.3, R2.2, R6.2, ST7735_MODULE1.2, SW1.2 (C), SW1.4, U1.1 (GND/ADJ), U2.9 (GND)
unnamed: R1.2, U2.3 (CH_PD)
unnamed: R4.2, R5.1
unnamed: R8.2, SW1.3 (B)
unnamed: R9.2, SW1.1 (A)
unnamed: R9.1, R10.2

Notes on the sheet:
LED SCK SDA A0 RESET CS GND VCC
Note: 10R for R7 is the minimum recommended value. Higher values reduce screen brightness.

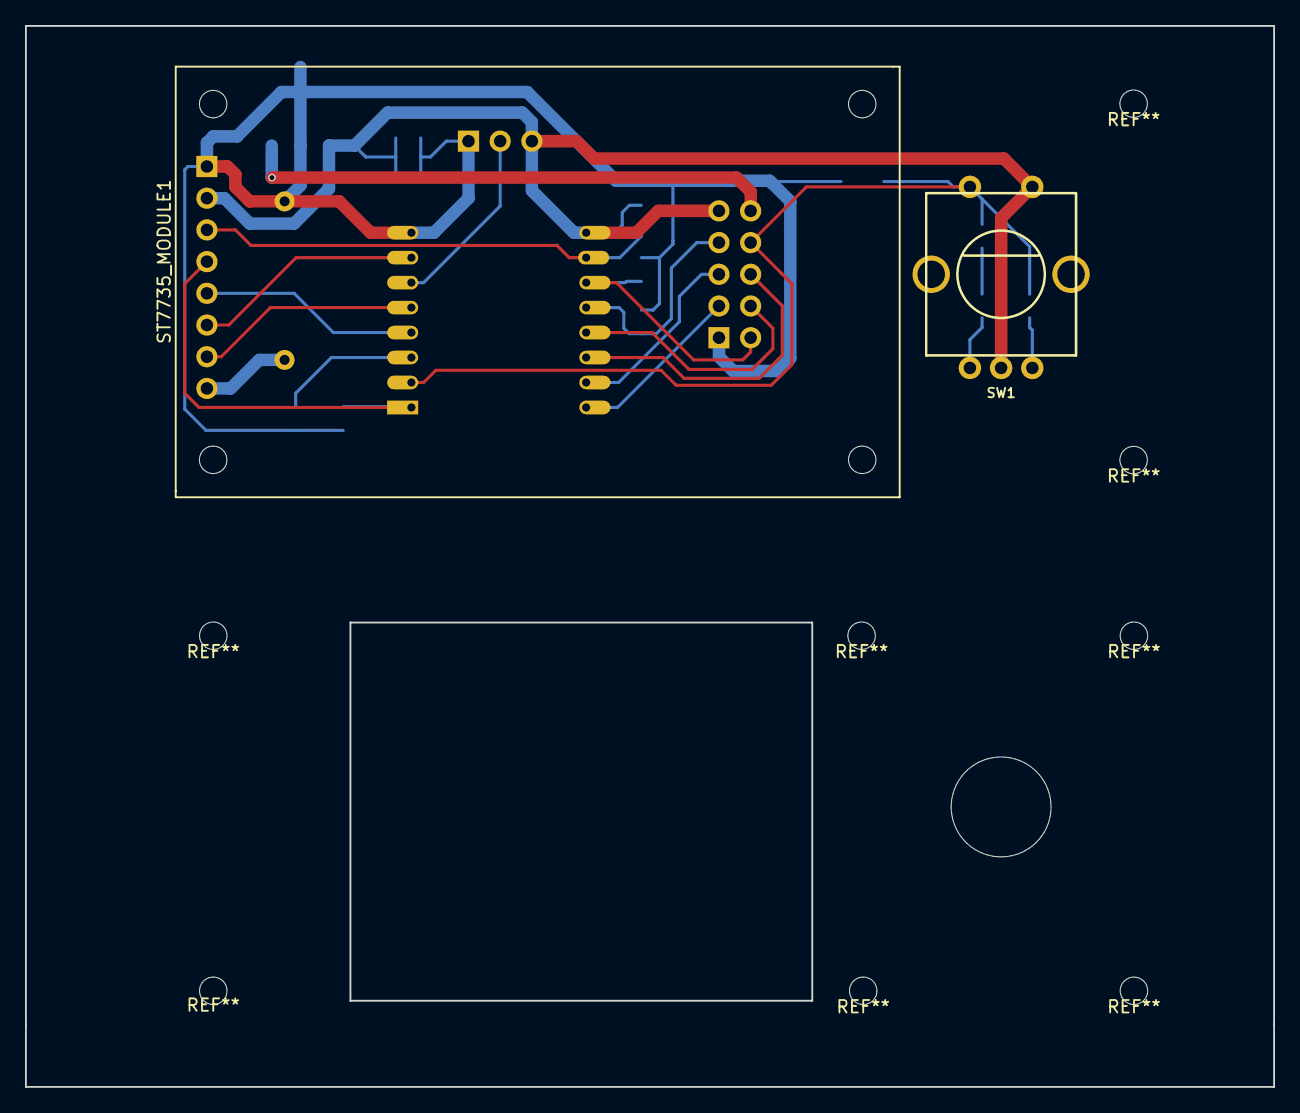
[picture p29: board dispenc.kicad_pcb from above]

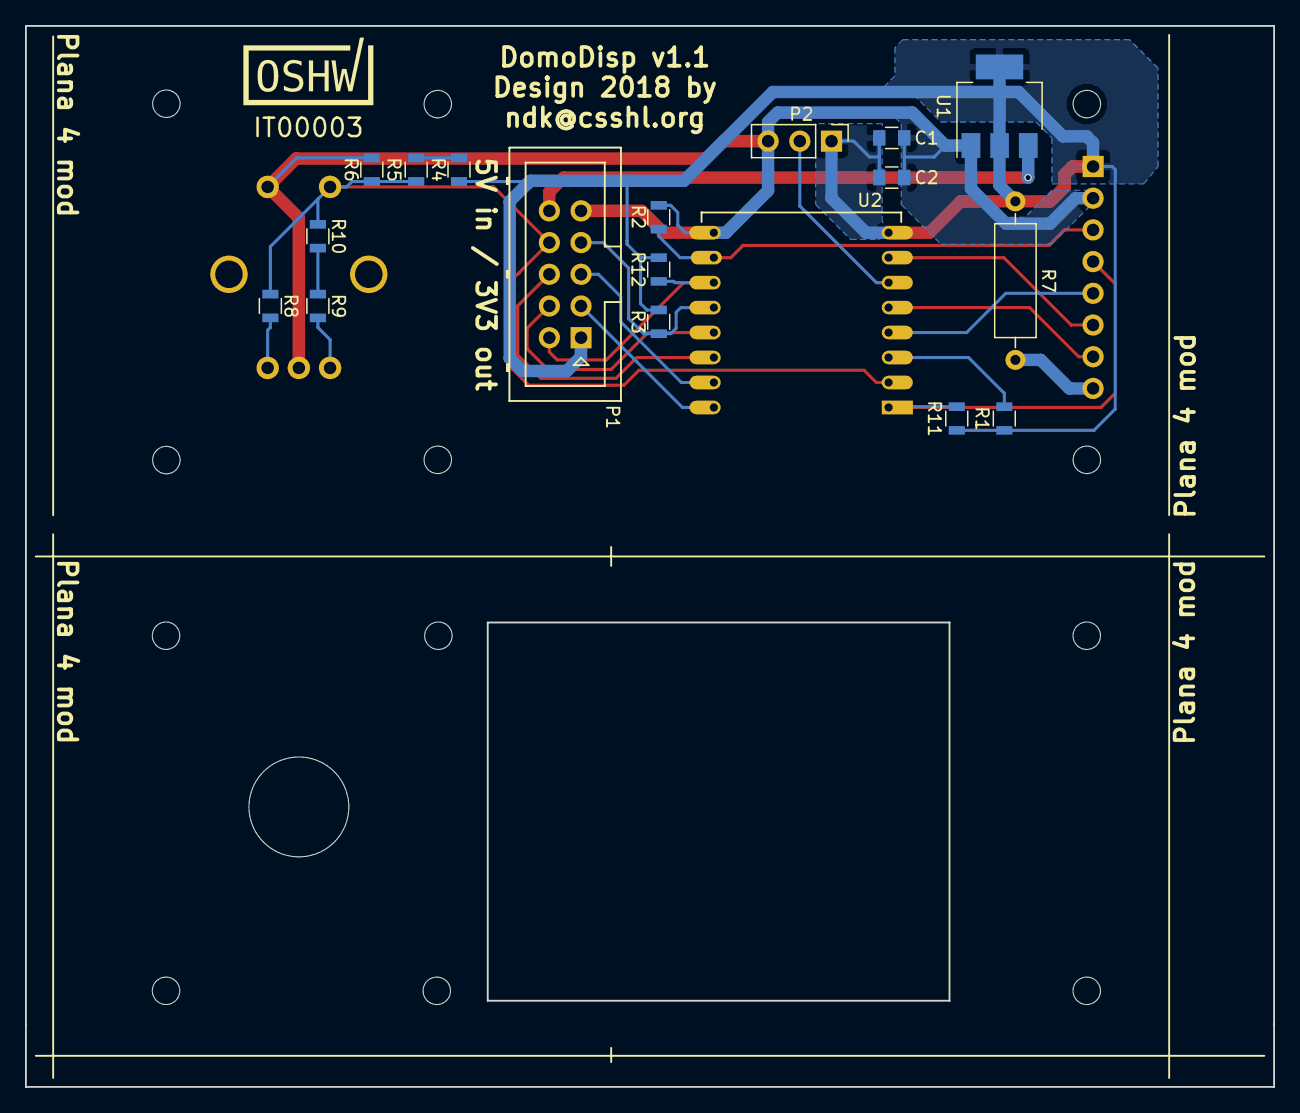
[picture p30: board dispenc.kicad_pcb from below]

Board: 2 copper layers, 100.0 x 85.0 mm, 21 parts (19 on the bottom side), 22 nets.

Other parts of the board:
OSHW_Mono_0.25_Scale: IT00003; OSHW_Mono_0.25_Scale
R12: 10k; R_0805

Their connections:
+3V3: R12.1; also elsewhere on the board
/DBG: R12.2; also elsewhere on the board

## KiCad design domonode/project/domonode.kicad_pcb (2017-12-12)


Board: 2 copper layers, 95.0 x 99.8 mm, 48 parts (0 on the bottom side), 45 nets.

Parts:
BOX: Enclosure_DIN_6p_nomargin
C1: C; c_elec_10x10
C2: 10u; C_0805
C3: 100n; C_0805
D1: LED; D_0805
F1: FUSE; Fuseholder5x20_horiz_SemiClosed_Casing10x25mm
JP1: JUMPER; Pin_Header_Straight_1x02_Pitch2.54mm
JP2, JP3: Jumper; Pin_Header_Straight_1x02_Pitch2.54mm
P1, P2: CONN_01X03; AK300-3
P3, P4: CONN_2x5; Multicomp_MC9A12-1034_2x05x2.54mm_Straight
P5: CONN_01X06; Pin_Header_Straight_1x06
P6, P7, P8, P9: CONN_01X02; Pin_Header_Straight_1x02
Q1, Q2, Q3, Q4: 2n7002; SOT-23
R1, R3, R4, R5, R6, R11, R12, R13: 10k; R_0805
R2, R7, R8, R9, R10, R14, R15, R16, R17: 1k; R_0805
RL1, RL2, RL3, RL4: Omron_G3MB-202; G3MB
U1: HLK-PM01; ACDC-HLK+ND
U2, U4: AMS1117-3.3; SOT-223
U3: ESP-12
VR1: VR; RV_Disc_D15.5_W4.2_P7.5

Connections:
+3V3: C2.1, C3.1, P3.1, R3.1, R4.1, R5.1, R6.1, U2.2, U2.4, U3.8
+5V: C1.1, P3.10, R7.2, R8.2, R9.2, R10.2, RL1.3, RL2.3, RL3.3, RL4.3, U1.4, U2.3
/ADC: P3.8, U3.2
/DBG: P3.2, R5.2, U3.11
/L: F1.1, P1.1, RL1.2, RL2.2, RL3.2, RL4.2
/N: P1.2, U1.2, VR1.1
/PROG: P3.7, R6.2, U3.12
/P_GND: D1.1, JP3.2, P4.9, P5.6, U4.1
/P_PROG: JP3.1, P4.7
/P_RXD: P4.5, P5.3
/P_TXD: P4.3, P5.2
/RL1: R2.1, U3.10
/RL2: R16.1, U3.5
/RL3: R14.1, U3.7
/RL4: R15.1, U3.6
/RXD: P3.5, U3.15
/SCL: P3.4, U3.13
/SDA: P3.6, U3.14
/TXD: P3.3, U3.16
GND: C1.2, C2.2, C3.2, P3.9, Q1.2, Q2.2, Q3.2, Q4.2, R1.2, R11.2, R12.2, R13.2, U1.3, U2.1, U3.9
unnamed: D1.2, R17.1
unnamed: F1.2, U1.1, VR1.2
unnamed: JP1.1, U3.4
unnamed: JP1.2, R4.2, U3.1
unnamed: JP2.1, P4.1
unnamed: JP2.2, U4.2, U4.4
unnamed: P4.10, R17.2
unnamed: P5.4, U4.3
unnamed: P6.1, R7.1
unnamed: P6.2, Q3.3, RL3.4
unnamed: P7.1, R8.1
unnamed: P7.2, Q1.3, RL1.4
unnamed: P8.1, R9.1
unnamed: P8.2, Q2.3, RL2.4
unnamed: P9.1, R10.1
unnamed: P9.2, Q4.3, RL4.4
unnamed: Q1.1, R1.1, R2.2
unnamed: Q2.1, R13.1, R16.2
unnamed: Q3.1, R11.1, R14.2
unnamed: Q4.1, R12.1, R15.2
unnamed: R3.2, U3.3
RL1P: P2.3, RL1.1
RL2P: P2.2, RL2.1
RL3P: P2.1, RL3.1
RL4P: P1.3, RL4.1

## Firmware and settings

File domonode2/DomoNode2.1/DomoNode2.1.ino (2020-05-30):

/*
 * Configure flash for 4M (1M SPIFFS)
 * Remember to configure your default settings in data/cfg.json and upload it as LittleFS (*NOT* SPIFFS!)
*/
#include "globals.h"
#include "web.h"
#include "io.h"
#include "config.h"

void setup() {
  Serial.begin(115200);
//  Serial.println("\nStartup");

  Wire.begin();

  if(!disk.begin()) { // By default autoformat is active
//    Serial.println("Error initializing filesystem");
    while(true) delay(5000);
  }

  readConfig();

  pinMode(RL_1, OUTPUT);
  pinMode(RL_2, OUTPUT);
  pinMode(RL_3, OUTPUT);
  pinMode(RL_4, OUTPUT);
  PCA9555Status s=ext.begin();
  if(PCA9555Status::OK != s) {
//    Serial.println("Error initializing PCA9555");
    while(true) delay(5000);
  }
  ext.portMode(PCA9555Port::A, 0b11111100); // Port A mixed
  ext.portMode(PCA9555Port::B, 0b00000000); // Port B as ouput (LEDs)
  ext.inputInv(0b0000000011111100); // Invert inputs, to read '1' when 220V is applied

  relay(1, RL_OFF);
  relay(2, RL_OFF);
  relay(3, RL_OFF);
  relay(4, RL_OFF);
  relay(5, RL_OFF);
  relay(6, RL_OFF);
  ext.digitalWrite(LED_USER, LED_OFF);

  WiFi.persistent(false); // Avoid wear-out
  WiFi.mode(WIFI_AP_STA);
  WiFi.hostname(conf.host);

  if(conf.apname[0]) {
    WiFi.softAP(conf.apname, conf.appass);
    // Configure AP as captive portal *before* trying connections in STA mode
    delay(500); // Small delay to stabilize
    IPAddress apip=WiFi.softAPIP();
    //Serial.println(apip);
    dnsServer.setErrorReplyCode(DNSReplyCode::NoError);
    dnsServer.start(53, "*", apip);
  }

  for(int sta=0; sta<MAXSTA && conf.ssid[sta][0]; ++sta) {
    wifiMulti.addAP(conf.ssid[sta], conf.pass[sta]);
  }
}

// Flashes LED_USER with given semiperiod (in ms). If 0, turn LED off
void flash_user(int semip) {
  static long lastflash=0;
  static bool user_led=LED_OFF;
  if(!semip) {  // Turn LED off
    status[ST_LDU]='0';
    if(LED_ON==user_led) {
      user_led=LED_OFF;
      lastflash=0;
      ext.digitalWrite(LED_USER, LED_OFF);
    }
  } else {
    status[ST_LDU]='F';
    if(t-lastflash > semip) { // Flash LED
      lastflash=t;
      user_led=!user_led;
      ext.digitalWrite(LED_USER, user_led);
    }
  }

}

void loop() {
  static long conn_changed=0;
  static bool ota_started=false, ota_flashing=false;
  static enum State s=RESET;
  static bool conn_led=LED_ON;

  t=millis();
  bool conn=(WiFi.status() == WL_CONNECTED) || (wifiMulti.run() == WL_CONNECTED);

  if(conn) {
    if(!ota_started) {
      // Perform operations that need to run only once at connection
      // Avoid i2c comm if not needed
      conn_led=LED_ON;
      ext.digitalWrite(LED_CONN, conn_led);

      // Announce services
      MDNS.begin(conf.host);

      /* setup the OTA server once we're connected and have obtained an IP */
      ArduinoOTA.setHostname(conf.host);
      ArduinoOTA.onStart([]() {
        ext.writePort(PCA9555Port::B, 0b11111111); // All LEDs on
        disk.end();
      });
      ArduinoOTA.onProgress([](unsigned int progress, unsigned int total) {
        static int last=0;
        static bool l=LED_OFF;
        l=!l;
        ext.digitalWrite(LED_USER, l);

        int n=(6*progress)/total;
        if(n==last) return;
        last=n;
        switch(n) { // All fall-through
          case 6:
            led(LED_6, LED_OFF);
          case 5:
            led(LED_5, LED_OFF);
          case 4:
            led(LED_4, LED_OFF);
          case 3:
            led(LED_3, LED_OFF);
          case 2:
            led(LED_2, LED_OFF);
          case 1:
            led(LED_1, LED_OFF);
        }
      });
      ArduinoOTA.onEnd([]() {
        ext.writePort(PCA9555Port::B, 0b11111110); // All LEDs off except USER_LED
      });
      httpUpdater.setup(&httpServer);
      httpServer.on("/status", HTTP_GET, webstatus);
      httpServer.on("/set", HTTP_POST, webouts);
      //@@@TODO httpServer.on("/setup", HTTP_POST, webconf);
//      httpServer.on("/favicon.ico", HTTP_GET, web404);
      httpServer.onNotFound(webpage);
      httpServer.begin();

      MDNS.addService("http", "tcp", 80);

      ArduinoOTA.begin(true); // use mDNS

      ota_started=true;
      conn_changed=t;
    }
    if(ota_started) {
      //MDNS.update();
      httpServer.handleClient();  // handle web pages
      ArduinoOTA.handle();  // Handle updates (calls MDNS.update() )
      dnsServer.processNextRequest();
    }
  } else {
    // Not yet connected
    if(t-conn_changed > 400) {
      conn_changed=t;
      ext.digitalWrite(LED_CONN, conn_led);
      conn_led=!conn_led;
    }
  }

  /*
   * Your FSM goes here
   */
  // Just animate the LEDs
  if(0==t%1000) {
    static int b=0;
    static long l=0;
    if(l!=t) {
      led(LED_1+b, LED_OFF);
      b=(b+1)%6;
      led(LED_1+b, LED_ON);
      l=t;
    }
  }
}

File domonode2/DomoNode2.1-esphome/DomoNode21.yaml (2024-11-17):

esp8266:
  board: esp12e

i2c: # required for tca9555

tca9555:
  - id: exp0 # Consider only base IOs
    address: 0x20 # 20-27, 20 is the first expander, default would be 0x21

switch:
  - id: rl1
    name: "${upper_devicename} Relay 1"
    platform: gpio
    pin:
      number: GPIO15
  - id: rl2
    name: "${upper_devicename} Relay 2"
    platform: gpio
    pin:
      number: GPIO14
  - id: rl3
    name: "${upper_devicename} Relay 3"
    platform: gpio
    pin:
      number: GPIO13
  - id: rl4
    name: "${upper_devicename} Relay 4"
    platform: gpio
    pin:
      number: GPIO12
  - id: rl5
    name: "${upper_devicename} Relay 5"
    platform: gpio
    pin:
      tca9555: exp0
      number: 0
      mode: output
      #inverted: true
  - id: rl6
    name: "${upper_devicename} Relay 6"
    platform: gpio
    pin:
      tca9555: exp0
      number: 1
      mode: output
      #inverted: true

output:
  - id: pin_ledusr
    platform: gpio
    pin:
      tca9555: exp0
      number: 9
      mode: output
      #inverted: true
  - id: pin_led1
    platform: gpio
    pin:
      tca9555: exp0
      number: 10
      mode: output
      #inverted: true
  - id: pin_led2
    platform: gpio
    pin:
      tca9555: exp0
      number: 11
      mode: output
      #inverted: true
  - id: pin_led3
    platform: gpio
    pin:
      tca9555: exp0
      number: 12
      mode: output
      #inverted: true
  - id: pin_led4
    platform: gpio
    pin:
      tca9555: exp0
      number: 13
      mode: output
      #inverted: true
  - id: pin_led5
    platform: gpio
    pin:
      tca9555: exp0
      number: 14
      mode: output
      #inverted: true
  - id: pin_led6
    platform: gpio
    pin:
      tca9555: exp0
      number: 15
      mode: output
      #inverted: true

light:
  - id: ledconn
    platform: status_led
    #name: "${upper_devicename} Led Conn"
    #output: pin_ledconn
    pin:
      tca9555: exp0
      number: 8
      mode: output
      #inverted: true

  - id: ledusr
    platform: binary
    name: "${upper_devicename} Led Usr"
    output: pin_ledusr
    restore_mode: ALWAYS_OFF
  - id: led1
    platform: binary
    name: "${upper_devicename} Led 1"
    output: pin_led1
    restore_mode: ALWAYS_OFF
  - id: led2
    platform: binary
    name: "${upper_devicename} Led 2"
    output: pin_led2
    restore_mode: ALWAYS_OFF
  - id: led3
    name: "${upper_devicename} Led 3"
    platform: binary
    output: pin_led3
    restore_mode: ALWAYS_OFF
  - id: led4
    platform: binary
    name: "${upper_devicename} Led 4"
    output: pin_led4
    restore_mode: ALWAYS_OFF
  - id: led5
    platform: binary
    name: "${upper_devicename} Led 5"
    output: pin_led5
    restore_mode: ALWAYS_OFF
  - id: led6
    platform: binary
    name: "${upper_devicename} Led 6"
    output: pin_led6
    restore_mode: ALWAYS_OFF

binary_sensor:
  - id: in1
    name: "${upper_devicename} In 1"
    platform: gpio
    pin:
      tca9555: exp0
      number: 2
      mode: input
      #inverted: true
  - id: in2
    name: "${upper_devicename} In 2"
    platform: gpio
    pin:
      tca9555: exp0
      number: 3
      mode: input
      #inverted: true
  - id: in3
    name: "${upper_devicename} In 3"
    platform: gpio
    pin:
      tca9555: exp0
      number: 4
      mode: input
      #inverted: true
  - id: in4
    name: "${upper_devicename} In 4"
    platform: gpio
    pin:
      tca9555: exp0
      number: 5
      mode: input
      #inverted: true
  - id: in5
    name: "${upper_devicename} In 5"
    platform: gpio
    pin:
      tca9555: exp0
      number: 6
      mode: input
      #inverted: true
  - id: in6
    name: "${upper_devicename} In 6"
    platform: gpio
    pin:
      tca9555: exp0
      number: 7
      mode: input
      #inverted: true

wifi:
  ssid: !secret wifi_ssid
  password: !secret wifi_password
  fast_connect: true

  # Enable fallback hotspot (captive portal) in case wifi connection fails
  ap:
    ssid: "${upper_devicename}"
    password: !secret wifi_fallback_pass

captive_portal:

# Enable logging
logger:
  baud_rate: 0 # Do not log over serial port

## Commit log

2017-12-12 Added protocol documentation and design files
    [domonode-B.Cu.gbl, domonode-B.Mask.gbs, domonode-B.Paste.gbp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]
2018-01-03 Specified KiCAD version used
2018-01-08 Upgraded design of DomoNode-inout to 1.1.1; removed version from dir name
    [domonode-inout-B.Cu.gbl, domonode-inout-B.Mask.gbs, domonode-inout-B.Paste.gbp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]
2018-01-08 Removed version from dir name for DomoNode
    [domonode-B.Cu.gbl, domonode-B.Mask.gbs, domonode-B.Paste.gbp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]
2018-01-08 Published current DomoDisp iteration (1.1)
    [dispenc-B.Cu.gbl, dispenc-B.Mask.gbs, dispenc-B.Paste.gbp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]
2018-01-09 DomoDisp is now certified by OSHWA (IT000003)
    [dispenc-B.Cu.gbl, dispenc-B.Mask.gbs, dispenc-B.Paste.gbp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]
2018-01-09 Fuzzyed KiCAD version
2018-05-10 Added forgot design files for domonode-inout (1.1.1)
    [domonode-inout.kicad_pcb, domonode-inout.sch]
2018-05-10 Added initial (untested) version of design files for domonode-inputs
    [domoinputs.kicad_pcb, domoinputs.sch]
2018-05-11 Renamed domonode-inputs project files, replaced connectors, reduced isolation for 230V to 1.5mm (requires a PCB with solder mask)
    [domonode-inputs.kicad_pcb, domonode-inputs.sch]
2018-05-13 Updated DomoNode-Inout to 1.1.2 (improved connectors footprints)
    [domonode-inout-B.Cu.gbl, domonode-inout-B.Mask.gbs, domonode-inout-B.Paste.gbp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]
2018-05-31 Reorganized DomoNode-Inputs files and added gerbers
    [domonode-inputs.kicad_pcb, domonode-inputs.sch]
2018-05-31 Added designs for DomoSwitch and panelized gerbers
    [DomoSwitch.kicad_pcb, DomoSwitch.sch]
2018-06-12 Added missing bottom-soldermask in pads for 220V inputs
    [domonode-inputs.kicad_pcb]
2018-06-16 Updated DomoNode-Inputs design files: - added component values in schematic (w/ minor changes for readability) - changed X2 capacitors footprint - moved filter capacitors to a regular pattern, where 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
    [domonode-inputs.kicad_pcb, domonode-inputs.sch]
2018-06-28 DomoNode-Inout: Fixed a really stupid error (swapped SCA/SCL on PCA9555); changed connector layout in schematic (from 1x10 to 2x5) for better readability
    [domonode-inout-B.Cu.gbl, domonode-inout-B.Mask.gbs, domonode-inout-B.Paste.gbp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]
2019-09-14 Added warning about physical dimensions of DIN rail enclosure
2020-02-29 Initial DomoNode2.0 design files
    [brd-logic.sch, domonode2.kicad_pcb, domonode2.sch]
2020-04-19 Slightly revised I2C memory address size detection algorithm
2020-05-24 Published DomoNode 2.1 design files and included docs about usable security chips
    [brd-logic.sch, domonode2.kicad_pcb, domonode2.sch]
2020-05-30 Replaced code zipfile with actual files (to keep mods in git history)
    [DomoNode2.1.ino, config.cpp]
2020-09-13 Added designs for DomoDisp enclosure for 504 wall box
    [Front.FCStd, Front.stl, Support.FCStd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]
2020-09-13 Referenced the DomoDisp enclosure from the root readme
2021-11-09 Update README.md
    https://forum.kicad.info/t/warning-avoid-all-links-to-kicad-pcb-org-use-kicad-org/31521
